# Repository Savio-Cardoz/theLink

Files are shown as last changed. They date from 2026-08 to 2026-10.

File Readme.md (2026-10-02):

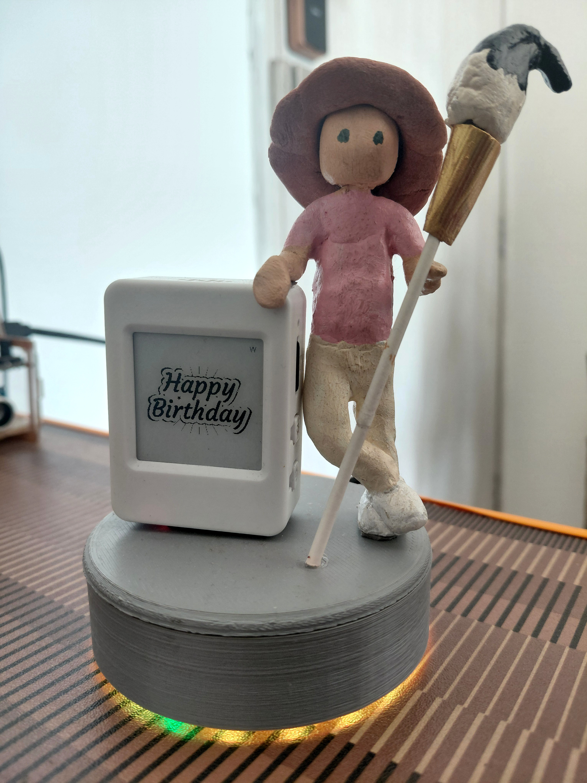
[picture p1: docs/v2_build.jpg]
theLink


# theLink

theLink is a device to send a surprise to a friend that quietly turns up on their
desk — no buzzing phone, no notification. The message arrives as a picture on
the e-paper screen, a glow from the LED ring, maybe a sound from the speaker.

Everything lives on one small waveshare unit, and one extra ring of LEDs makes it glow.

- Built right in: 1.54-inch e-paper display, ESP32-S3 (Wi-Fi + Bluetooth), speaker, microphone, microSD card reader
- I've added a 16-LED NeoPixel ring (the notification LED)
- Messages arrive over Wi-Fi via MQTT (default broker: `mqtt://broker.emqx.io`)
- First-time setup over Bluetooth by scanning a QR code

---

## 1. What is it

**The unit** — a Waveshare 1.54-inch ESP32-S3 e-paper module. It comes as one
package and already contains:

| Piece | What it does |
|---|---|
| E-paper display (200x200) | Shows images, all day, with almost no power |
| ESP32-S3 chip | The brain — Wi-Fi + Bluetooth built in |
| Speaker | Plays sound files |
| Microphone | (available for future projects) |
| microSD reader | Stores images and sounds on a card |
| SHTC3 temperature + humidity sensor | Reports the air around it, every 5 minutes |
| PCF85063 real-time clock | Keeps the time across a restart, so a rebooted unit needs no network to know it. Runs on the board's 3v3 rail, so it does not survive a power cut |

**Additional**

| Piece | Why |
|---|-----|
| 16-LED NeoPixel ring | The glowing "notification LED", data pin wired to GPIO 2 |
| microSD card (FAT32) | Holds the images and sounds the device downloads |
| USB-C data cable | For the one-time software flash |
| External Button  | For the one-time Wi-Fi setup (Bluetooth) |
| Computer | For the one-time software flash |
| Android phone | For the ESP BLE Provisioning app and IoTHome MQTT dashboard builder app.

**Software you'll use:**

- **MQTTX** — a free app (desktop or phone) for sending and watching messages. This is how the surprise travels to my friend's via theLink.
- **Espressif Provisioning** app (phone) — scans the QR code on the e-paper to give the device a Wi-Fi name and password.

---

## 2. First power-up

1. **Flash the software once.** This needs the ESP-IDF environment set up first
   (only once per computer, and repeated for every new terminal):

   ```powershell
   $env:IDF_PATH = "C:\Espressif\frameworks\esp-idf-v5.4.1"
   & "$env:IDF_PATH\export.ps1"
   ```

   Then, from the project folder:

   ```bash
   python3 scripts/build.py flash
   ```

2. **Reset Provisioning:** hold the reset button at the rear
   (GPIO 3) down while powering it up and keep holding for about 1 second.
3. **Power on.** After a moment the e-paper shows a QR code and the LED ring starts pulsing.
4. **Add Wi-Fi:** open the Espressif Provisioning app, scan the QR code, and enter the Wi-Fi network name and password.
5. **Done.** The LED ring stops pulsing once it connects — the device is ready.

### LED ring indicators during provisioning

The ring shows which stage of setup it is in:

| Effect | What it means |
|---|---|
| Fast blue pulse (every 0.5 s) | Provisioning is active — it's waiting for a phone |
| Medium blue pulse (every 1.5 s) | A phone is connected over Bluetooth |
| Slow blue pulse (every 3 s) | It connected to the Wi-Fi |
| Ring does behaves as MQTT messages say | Setup is complete |

---

## 3. MQTT Communication

MQTT is how a message travels from me to my friend's theLink over Wi-Fi. It works like a post office:

- **Broker** = the post office in the middle (there's a free public one at `broker.emqx.io`).
- **Topic** = a mailbox name. The device checks certain mailboxes and ignores the rest.
- **Message** = the letter inside the mailbox. JSON text

**Heads-up:** `0A1B2C3D4E5F` in the topics below is a placeholder — it stands for
the 6-byte MAC address of the ESP32 chip in use. Section 4 shows 
how to find the MAC and swap it in.

Topics come in two flavours:

| Kind | Looks like | Meaning |
|---|---|---|
| `cmd/` (commands) | `thelink/0A1B2C3D4E5F/cmd/rgb` | Mailboxes the device **reads** — where to post messages |
| `evt/` (events) | `thelink/0A1B2C3D4E5F/evt/led` | Mailboxes the device **writes** — its replies |

**First 60 seconds with MQTTX:**

1. Open MQTTX and add a connection to `broker.emqx.io` (port `1883`).
2. Subscribe (listen) to topic `thelink/0A1B2C3D4E5F/evt/#` (remember: replace `0A1B2C3D4E5F` with device's ID).
3. Publish (send) to topic `thelink/0A1B2C3D4E5F/cmd/rgb` this message:

   ```json
   { "pattern": "rainbow_cycle" }
   ```

4. The ring goes rainbow. First message delivered

If you built the firmware with a broker URL or credentials (see
[MQTT broker settings](#mqtt-broker-settings)), MQTTX has to point at the same
broker, with the same username and password.

---

## 4. Find the device ID

Every example in this guide uses the placeholder device ID `0A1B2C3D4E5F`.
**Your device has its own.** It is the 6-byte factory MAC address of your board,
written as uppercase hex with no dashes — format `UUVVWWXXYYZZ`.

How to see yours:

- **Boot log:** the serial monitor prints `Device ID: UUVVWWXXYYZZ` at startup.

Whatever it is, swap it in wherever you see `0A1B2C3D4E5F` below.

---

## 5. The messages you can send — copy and paste ready

Pick a section, copy the topic, copy the message, and paste them into MQTTX.

### 5.1 Show an image — `cmd/display`

Downloads a picture from the server, saves it on the SD card, and shows it on the e-paper.

- **Topic:** `thelink/0A1B2C3D4E5F/cmd/display`
- **Publish this:**

  ```json
  {
    "download": "http://example.com/myphoto.bin",
    "filename": "myphoto.bin"
  }
  ```
- **You should see:** the e-paper refresh and show the new image.

| Field | Type | Required | Description |
|---|---|---|---|
| `download` | string | Yes | The web address (URL) of the image |
| `filename` | string | Yes | What to call the file on the SD card (`/sdcard/…`) |

**Before you send an image — turn your photo into e-paper format.**

The screen is monochrome and 200x200. Ordinary JPG/PNG files won't work: you first
convert yours into the special `.bin` format the screen understands, host it on your
own HTTP server, then point the message at it.

1. **Convert your photo** with the included script (run it on your computer, in the
   project folder):

   ```bash
   python3 scripts/png_to_epaper.py myphoto.png myphoto.bin
   ```

   Useful extra options: `--threshold <0-255>` (brightness cut-off, default 128),
   `--invert` (swap black and white), and `--preview` (saves a `_preview.png` so you
   can check the result before sending).

2. **Host the file on your own HTTP server** — it must be reachable from the device.
   The quickest way, from the folder containing the `.bin`:

   ```bash
   python3 -m http.server
   ```

   Now your file is available at `http://<your-server-ip>:8000/myphoto.bin`.

3. **Use that link as `download`** — the URL of the `.bin` on your server goes into
   the message:

   ```json
   {
     "download": "http://192.168.1.50:8000/myphoto.bin",
     "filename": "myphoto.bin"
   }
   ```

Notes: images must be LVGL I8 format (indexed 8-bit, 200x200, with a 256-colour
palette) — exactly what `png_to_epaper.py` produces.

---

### 5.2 The RGB LED ring — `cmd/rgb`

The most fun one. The ring has 16 LEDs and supports patterns, colours, brightness,
per-LED colours, and an auto-off timer. Every field is optional — only send what you
want to change.

- **Topic:** `thelink/0A1B2C3D4E5F/cmd/rgb`

**Solid colour:**

```json
{
  "enable": true,
  "pattern": "solid_color",
  "color": { "h": 210, "s": 100, "v": 60 }
}
```

**Rainbow slowly cycling:**

```json
{
  "pattern": "rainbow_cycle",
  "speed": 40
}
```

**Per-LED colours (LED 0 red, LED 1 green, LED 2 off, rest skipped):**

```json
{
  "pixels": ["#FF0000", "#00FF00", null],
  "brightness": 75
}
```

**Turn on, then off by itself after 30 seconds (timer + colour as hex):**

```json
{
  "pattern": "scanner",
  "color": "#00AAFF",
  "duration": 30
}
```

**Turn the ring off:**

```json
{ "enable": false }
```

- **You should see:** the ring change immediately, and a reply arrive on `evt/led` with the new state.

**Patterns you can use:**

| Pattern | Description |
|---|---|
| `off` | Turn the strip off |
| `solid_color` | Single steady colour |
| `rainbow_cycle` | Smooth rainbow cycling across all LEDs |
| `theater_chase` | Theatre-style chasing lights |
| `color_wipe` | One colour wipes across the ring |
| `scanner` | A light sweeping back and forth |
| `fade` | Gentle breathing fade |

**All the fields:**

| Field | Type | Values / default | Description |
|---|---|---|---|
| `enable` | bool | `true` / `false` | Master on/off; `false` turns the ring off immediately |
| `pattern` | string | see table above | Which pattern to run (also switches the ring on) |
| `color` | string or object | `"#RRGGBB"`, or `{"h":0-360,"s":0-100,"v":0-100}`, or `{"r","g","b":0-255}` | The colour to use |
| `brightness` | number | 0–100 (default 100) | Global brightness, dims everything |
| `speed` | number | 5–5000 ms (default 20) | How fast patterns animate — lower is faster |
| `pixels` | array | up to 16 entries | Colour each LED by hand; `null` skips an LED and overrides `pattern` while present |
| `duration` | number | seconds | Auto-off after this long (0 or absent = stay on) |
| `persist` | bool | default `true` | Save the state to the SD card so it survives a reboot |

---

### 5.3 Notification alert — `cmd/notification`

A shortcut that turns on the ring with a pattern (the same patterns as `cmd/rgb`).

- **Topic:** `thelink/0A1B2C3D4E5F/cmd/notification`
- **Publish this:**

  ```json
  {
    "message": "scanner"
  }
  ```

- **You should see:** the ring start the `scanner` pattern.

| Field | Type | Required | Description |
|---|---|---|---|
| `message` | string | Yes | Pattern name (same list as section 5.2) |

---

### 5.4 Play a sound — `cmd/audio`

Plays an audio file through the speaker. The file can already be on the SD card,
or the device can download it first.

**Play a file already on the SD card:**

- **Topic:** `thelink/0A1B2C3D4E5F/cmd/audio`
- **Publish this:**

  ```json
  {
    "download": "",
    "filename": "alert.wav",
    "volume": 80
  }
  ```

**Download a file, then play it:**

  ```json
  {
    "download": "http://example.com/alert.wav",
    "filename": "alert.wav",
    "volume": 80
  }
  ```

- **You should hear:** the sound over the speaker.

| Field | Type | Required | Description |
|---|---|---|---|
| `download` | string | Yes | Web address of the sound — use an empty string `""` if the file is already on the SD card |
| `filename` | string | Yes | The file to play (saved to `/sdcard/…` when downloading) |
| `volume` | number | No | Volume 0–100 |

---

### 5.5 Update the firmware — `cmd/ota`

Downloads a brand-new version of the device software, shows "Update in progress"
on the screen, then restarts itself with the new code.

- **Topic:** `thelink/0A1B2C3D4E5F/cmd/ota`
- **Publish this:**

  ```json
  {
    "download": "https://example.com/theLink_esp32s3.bin",
    "version": "0.4.0"
  }
  ```

- **You should see:** "Update in progress" on the e-paper, then the device reboots.
  Progress replies arrive on `evt/ota` (`started`, `downloaded`, `rebooting`, `failed`).

| Field | Type | Required | Description |
|---|---|---|---|
| `download` | string | Yes | Web address of the firmware file (an ESP-IDF app image `.bin`) |
| `version` | string | No | Just for the logs and events |

Like images (section 5.1), the firmware file must first exist on your own HTTP
server — put the `.bin` somewhere the device can reach and point `download` at
that file's URL. No conversion step is needed; the firmware is already an ESP-IDF
app image.

---

### 5.6 Control the logs — `cmd/log`

Changes how loudly the device talks on `evt/log`. Handy when debugging.

- **Topic:** `thelink/0A1B2C3D4E5F/cmd/log`

**Set the log level to debug (most talkative):**

```json
{
  "action": "set_level",
  "level": "debug"
}
```

**Check the current level:**

```json
{
  "action": "get_level"
}
```

| Field | Type | Required | Description |
|---|---|---|---|
| `action` | string | Yes | `"set_level"` or `"get_level"` |
| `level` | string | for `set_level` | `"error"`, `"warn"`, `"info"`, `"debug"`, `"verbose"`, or `"none"` |

---

### 5.7 Check on the status of theLink — `cmd/status`

Query the device for its status, what is its state.

- **Topic:** `thelink/0A1B2C3D4E5F/cmd/status`

**Ask for the status (any payload works, even an empty one):**

```json
{}
```

- **You should see:** a reply on `evt/status` (section 6) with the current
  firmware version, the LED pattern, the image on the e-paper, the current time
  and where it came from, how much room is
  left on the SD card and a few
  supporting details.

The command takes no fields — it is a bare query, so an empty message is fine.
Nothing is changed by sending it, and the reply is **not** retained.

---

### 5.8 Set the timezone — `cmd/timezone`

Tell the device where it is, so it can report local time and not just UTC. It
does not look this up from the IP address: you declare it.

- **Topic:** `thelink/0A1B2C3D4E5F/cmd/timezone`

**For India (IST, UTC+05:30):**

```json
{
  "tz": "IST-5:30"
}
```

**For Germany in summer (CEST, UTC+02:00):**

```json
{
  "tz": "CEST-2"
}
```

| Field | Type | Required | Description |
|---|---|---|---|
| `tz` | string | Yes | The timezone as a POSIX string (see below) |

**The sign is inverted, and this trips everyone up.** A POSIX offset is the time
you **add to local time to reach UTC**. India is ahead of UTC by 5½ hours, so it
is `-5:30`, not `+5:30`. Writing `IST+5:30` would put the device five and a half
hours *behind* UTC.

**This is not an IANA name.** `"Asia/Kolkata"` will be rejected with a note in
the log rather than silently doing nothing, because the C library in this firmware
ships no timezone database to resolve it against. Use the POSIX form — any label
you like (`IST`, `CET`, whatever) followed by the offset.

The device logs the offset it actually ended up applying, so check the serial log
or `evt/log` if the local time looks wrong:

```
I (1234) TIME: timezone "IST-5:30" applied, UTC offset is +05:30
```

The setting is written to the SD card and survives a reboot. The `THELINK_TZ`
build option is only a factory default for a card that has never been told
otherwise.

**Daylight saving is not automatic.** A fixed offset like `IST-5:30` is correct
year-round for India, but a place that changes its offset will need a new
`cmd/timezone` when it does.

---

## 6. What the device sends back (events)

These are mailboxes the device **writes** to. Subscribe to them to watch what
theLink is doing.

### `evt/led` — the ring's state (retained)

Every time the ring accepts a command, the device replies with the full current
state. The message is **retained**, so anyone who subscribes later immediately
gets the latest state — no need to wait.

- **Topic:** `thelink/0A1B2C3D4E5F/evt/led`

```json
{
  "active": true,
  "pattern": "rainbow_cycle",
  "color": { "h": 210, "s": 100, "v": 60 },
  "brightness": 75,
  "speed": 40,
  "pixels": ["#FF0000", null],
  "cmd_id": 12
}
```

### `evt/ota` — firmware update progress

- **Topic:** `thelink/0A1B2C3D4E5F/evt/ota`

```json
{
  "status": "downloaded",
  "detail": "/sdcard/update.bin"
}
```

`status` is one of `started`, `downloaded`, `rebooting`, or `failed`.

### `evt/sensor` — temperature and humidity (retained)

The built-in SHTC3 sensor takes a reading shortly after boot and then every
5 minutes. The message is **retained**, so a dashboard that subscribes at any
time immediately gets the most recent reading instead of waiting for the next
one, and the device re-publishes it every time it reconnects to the broker.

- **Topic:** `thelink/0A1B2C3D4E5F/evt/sensor`

```json
{
  "temperature_c": 24.31,
  "humidity_pct": 41.19,
  "age_ms": 12430
}
```

| Field | Type | Description |
|---|---|---|
| `temperature_c` | number \| null | Air temperature in degrees Celsius |
| `humidity_pct` | number \| null | Relative humidity, 0-100 |
| `age_ms` | number | How long ago this reading was taken. Absent when there is no reading |

This topic is **publish-only** — there is no `cmd/sensor` command, because
there is nothing to configure about a thermohygrometer. To read the value right
now, use `cmd/status` (section 5.7), which folds the same numbers into its
`sensor` object.

If a read fails (sensor not yet powered, bus error, or a bad checksum) the
device logs a warning and keeps the previous reading rather than publishing a
blank one, so a stale number is never silently replaced by `null`. The
temperature and humidity fields are `null` only until the very first successful
sample. Each read is attempted three times before the cycle gives up, and the
first attempt is held back until about two seconds after boot so it does not
race the audio codec coming up on the same I2C bus.

At boot the driver also reads the sensor's ID register and logs it, e.g.
`SHTC3: ID 0x0910 (CRC ok)`. That is the quickest way to tell a working sensor
from a dead one: no ID line, or a CRC failure, means the part never identified
itself. See the troubleshooting table (section 7).

### `evt/status` — answer to `cmd/status`

- **Topic:** `thelink/0A1B2C3D4E5F/evt/status`

```json
{
  "version": "0.4.0",
  "rgb_pattern": "rainbow_cycle",
  "image": "/sdcard/dog.bin",
  "device_id": "0A1B2C3D4E5F",
  "sensor": {
    "temperature_c": 24.31,
    "humidity_pct": 41.19,
    "age_ms": 12430
  },
  "time": {
    "utc": "2026-09-26T06:12:33Z",
    "epoch_s": 1788297153,
    "local": "2026-09-26T11:42:33+05:30",
    "tz": "IST-5:30",
    "source": "sntp",
    "synced": true,
    "age_ms": 51230,
    "rtc": { "present": true, "valid": true }
  },
  "partition": "ota_0",
  "uptime_ms": 128430,
  "free_heap": 214032,
  "min_free_heap": 180112,
  "sdcard": { "mounted": true, "total_bytes": 31914983424, "free_bytes": 30012345678 },
  "build": { "date": "Sep 26 2026", "time": "11:42:07", "idf": "v5.4.1" }
}
```

| Field | Type | Description |
|---|---|---|
| `version` | string | Firmware version (matches `version.txt`) |
| `rgb_pattern` | string | LED pattern currently selected — one of `off`, `solid_color`, `rainbow_cycle`, `theater_chase`, `color_wipe`, `scanner`, `fade` |
| `image` | string \| null | Full SD path of the image **currently on the e-paper**, or `null` if nothing has been rendered yet |
| `device_id` | string | Same device ID you used in the topic |
| `sensor` | object | Cached temperature and humidity — `temperature_c`, `humidity_pct`, and `age_ms`. `null` values until the first sample succeeds. Same contents as `evt/sensor` |
| `time` | object | The current time, where it came from, and the RTC's state. See the table below |
| `partition` | string \| null | App partition being executed (`ota_0` in a production build) |
| `uptime_ms` | number | Milliseconds since boot |
| `free_heap` | number | Free internal heap, in bytes |
| `min_free_heap` | number | Lowest free heap reached since boot, in bytes |
| `sdcard` | object \| null | `mounted`, `total_bytes` and `free_bytes` of the SD card, or `null` if no card is present |
| `build` | object | `date`, `time` and IDF `version` of this build. Omitted if the build has no compile timestamp |

`image` only advances once a picture has been unpacked and pushed to the screen,
so it never claims to be showing an image that failed to download or render.
It starts out as `null` after a reboot and fills in once the e-paper has been
drawn.

`sensor` is a cache, not a live read: asking for the status never blocks on I2C,
so it stays fast. Use `age_ms` to tell a fresh reading from one taken at boot.

`sdcard` is `null` rather than zeroed when the card is absent, so a missing card
is never mistaken for a full one. Its sizes describe the FAT volume, meaning
filesystem overhead is already excluded — the numbers are what you can actually
store, not the card's advertised capacity.

#### The `time` object

| Field | Type | Description |
|---|---|---|
| `utc` | string \| null | The time in UTC, ISO 8601 with a `Z` suffix. `null` if no time has been established yet |
| `epoch_s` | number \| null | The same instant as a Unix timestamp |
| `local` | string \| null | Local time with its offset, e.g. `2026-09-26T11:42:33+05:30`. `null` until a timezone is declared |
| `tz` | string \| null | The timezone string in force, e.g. `IST-5:30`. `null` if none was ever set |
| `source` | string | `sntp` (corrected against an NTP server), `rtc` (restored from the RTC on boot), or `none` |
| `synced` | boolean | `true` only when `source` is `sntp` |
| `age_ms` | number \| null | How long ago the time was last established. `null` when it never has been |
| `rtc.present` | boolean | Whether a PCF85063 real-time clock answered on the I2C bus |
| `rtc.valid` | boolean | Whether the RTC is holding a calendar worth reading, either because it survived the last restart or because it was written since. `false` after a power cut, until SNTP writes it |

`source` is the field worth watching. A device showing `sntp` is telling the
truth. One showing `rtc` has restored its clock from the RTC and is running on that
until the network catches up — as trustworthy as a drift-free crystal, but not yet
confirmed. `none` means no time has been established at all, which is the expected
state straight after a power cut.

`local` and `tz` stay `null` until you send `cmd/timezone` (section 5.8). The
device does not assume UTC, because a dashboard that silently renders 5:30 as
"local" is worse than one that says it does not know.

The device syncs to `pool.ntp.org` as soon as it has a network address, and
re-checks hourly. It also keeps a PCF85063 real-time clock, which it writes on every
sync and reads at boot, so a unit that reboots without Wi-Fi still reports the right
time. That is the limit of it: the RTC is powered from the board's 3v3 rail and
there is no backup cell fitted, so a power cut resets it and the unit has to reach
SNTP before it knows the time. `source: none` on a freshly plugged-in unit is
expected, not a fault.

### `evt/log` — the device's diary

- **Topic:** `thelink/0A1B2C3D4E5F/evt/log`

```json
{
  "device_id": "0A1B2C3D4E5F",
  "level": "info",
  "tag": "app",
  "msg": "Display download complete"
}
```

---

## 7. Troubleshooting

| Problem | Try this |
|---|---|
| LED ring does nothing | Check power; make sure you flashed the firmware (section 2); check Data line connection |
| Ring pulses forever after setup | Wi-Fi credentials didn't save — factory reset (hold reset ~1 s at boot) and re-provision |
| Screen stays blank | Check the SD card is inserted, formatted FAT32, and your file was downloaded (watch `evt/led` isn't enough — check `evt` and the serial log) |
| Nothing happens / no `evt/led` reply | Wrong device ID in the topic, or the broker address doesn't match. Verify the device ID in the boot log |
| Image doesn't show | Convert it first with `python3 scripts/png_to_epaper.py` — it must be LVGL I8, 200x200, with a 256-colour palette, and hosted on your own HTTP server |
| Sound doesn't play | File must exist on the SD card (use `"download": ""` for a file already there) |
| `evt/sensor` never arrives | Start with `ID 0x….  (CRC ok)` and `SHTC3 attached at 0x70`, then the `I2C scan on SDA 47 / SCL 48:` line printed about two seconds after boot, which lists the addresses that answered. Treat it as a rough indication, not a device list: it shares the bus with the audio codec, and a probe that loses the bus to another task can miss a device that is working. A `swept 0x08..0x77:` line follows it with the totals (answered / did not acknowledge / timed out), and `sweep missed 0x…` warns outright when the scan contradicts a device that just answered — when you see that, the scan is wrong, not the device. The per-device attach lines (`SHTC3 attached at 0x70`, `PCF85063 attached at 0x51`) are the reliable evidence. A failed attach, or an `ID read 0xEFC8 NACKed at 0x70` at attach, is hardware — the sensor never identified itself. If the ID verifies but a read still fails, `measurement command 0x7866 NACKed at 0x70` means it answered the probe and the identity read but not the measurement, and `CRC mismatch` means the bus is noisy. A read is retried three times per cycle, then left to the next 5-minute tick |
| `time.source` stays `rtc` or `none` | SNTP has not completed. `TIME: SNTP started against pool.ntp.org` means it was started, so look for `synchronized with pool.ntp.org`. The device waits 2 minutes for the first correction and then logs that none arrived, but lwIP keeps retrying in the background and a later correction sets the clock as normal, so that warning alone is not a failure. If it never corrects, the network is blocking UDP 123, or DNS cannot resolve the pool. `none` is the expected state after a power cut until SNTP lands, because the RTC is powered from 3v3 and resets with the board; it is only a fault if it persists after the unit has synced once |
| `time.local` is `null` | No timezone has been declared. Send `cmd/timezone` (section 5.8) |
| `time.local` is hours off | The POSIX sign is inverted. `IST+5:30` is *behind* UTC by 5½ hours; India is `IST-5:30`. The device logs the offset it applied — `timezone "…" applied, UTC offset is +05:30` — so check that line against what you expected |
| `cmd/timezone` is ignored | Look for the reason in the log. A payload with no `tz` string, one that isn't JSON, or an IANA name containing `/` is rejected outright rather than applied |

---

## 8. Advanced: building and flashing (for maintainers)

This section is for the people updating the software itself. If you just want to
use the device, you can stop reading here.

### ESP-IDF environment

The IDF tools live in `$env:IDF_PATH`, which must point at an ESP-IDF install that
actually has its toolchain installed (e.g. `C:\Espressif\frameworks\esp-idf-v5.4.1`
for the Espressif installer layout). Tools and toolchains are not tied to a bare
`git clone` — running export from such a clone fails with `tool ... has no
installed versions`.

In a new PowerShell terminal:

```powershell
$env:IDF_PATH = "C:\Espressif\frameworks\esp-idf-v5.4.1"
& "$env:IDF_PATH\export.ps1"
```

Notes:

- Export must be repeated in every new terminal (environment variables are per-session).
- A stale `IDF_PATH` overrides the new value inside already-open terminals — restart after changing it.
- `scripts/build.py` and `scripts/flash_all.py` auto-locate the ESP-IDF Python environment, so they work without the export (the export is still needed to call `idf.py`, `esptool.py`, or `menuconfig` directly).
The project uses my [esp32_factory_app](https://github.com/Savio-Cardoz/esp32_factory_app.git) repo as the update flashing app. This app resides in the factory parition.

### Build profiles

A single switch selects the build profile. **Dev is the default** — a plain
`python3 scripts/build.py` gives a development build.

- **Dev** (default) — standard partition table **without OTA** (`partitions_dev.csv`). Flashed straight to the `factory` partition; the `esp32_factory_app` bootloader is not used. Builds go to `build-dev`.
- **Prod** — production partition table for OTA via the `esp32_factory_app` bootloader (`partitions.csv`: `factory` + `ota_0`). Builds go to `build`.

```bash
# Development build (no OTA) — default profile
python3 scripts/build.py
python3 scripts/build.py flash

# Production build (esp32_factory_app OTA)
python3 scripts/build.py -p Prod
python3 scripts/build.py -p Prod flash
```

Manual equivalents:

```bash
python3 $IDF_PATH/tools/idf.py -B build-dev build
python3 $IDF_PATH/tools/idf.py -B build-dev flash
python3 $IDF_PATH/tools/idf.py -B build -DSDKCONFIG_DEFAULTS="sdkconfig.defaults;sdkconfig.prod" build
```

For production, the main app is flashed to the `ota_0` partition and the
`factory` partition holds the bootloader app. Flash the whole stack (bootloader,
partition table, otadata, factory app + main app) with:

```bash
python3 scripts/flash_all.py -p COM6
```

### Configuration

Build-time options in `menuconfig` (`Example Configuration`):

| Option | Default | Description |
|---|---|---|
| `CONFIG_BROKER_URL` | `mqtt://broker.emqx.io` | MQTT broker address |
| `CONFIG_MQTT_USERNAME` | `""` | MQTT username (usually set at build time, see below) |
| `CONFIG_MQTT_PASSWORD` | `""` | MQTT password (usually set at build time, see below) |

#### MQTT broker settings

The first time you build, `scripts/build.py` asks for the broker URL and its
credentials and remembers them:

```
Broker URL [mqtt://broker.emqx.io]: mqtts://my-broker.example.com:8883
MQTT username: thelink
MQTT password: ********
Confirm password: ********
  broker url      : mqtts://my-broker.example.com:8883 (the prompt)
  mqtt username   : thelink (the prompt)
  saved to        : sdkconfig.secrets
```

They are stored in `sdkconfig.secrets`, a Kconfig overlay that the build appends
to `SDKCONFIG_DEFAULTS`. The file is gitignored, so the credentials never reach
the repository. Later builds read it silently — you answer the prompt once.

| Setting | Kconfig option | Environment variable |
|---|---|---|
| Broker URL | `CONFIG_BROKER_URL` | `THELINK_BROKER_URL` |
| Username | `CONFIG_MQTT_USERNAME` | `THELINK_MQTT_USERNAME` |
| Password | `CONFIG_MQTT_PASSWORD` | `THELINK_MQTT_PASSWORD` |

All three are ordinary menuconfig options as well, so you can set them by hand
if you prefer. **Leaving a field empty means "not specified"**: that field is
not written to the overlay and the menuconfig value keeps applying. The Broker
URL prompt is pre-filled with the URL the last build used, so pressing Enter
leaves your menuconfig broker alone rather than pinning a copy of it. A typed
URL is checked before it is accepted — it needs a host and one of the four
schemes esp-mqtt understands (`mqtt`, `mqtts`, `ws`, `wss`) — so a typo fails
at build time rather than on the device.

**Skipping the prompt is fine.** Press Enter at the username prompt and the
build carries on with no credentials, exactly as firmware before v0.4.0 did —
which is what an unauthenticated public broker such as `broker.emqx.io` wants.
The firmware logs a warning at boot and connects anonymously; a broker that
requires authentication will refuse the connection.

```bash
# Change the broker settings later
python3 scripts/build.py --reprompt

# Never be asked: use the cache if there is one, menuconfig if not
python3 scripts/build.py --no-prompt

# Supply them non-interactively (CI, scripted builds)
THELINK_BROKER_URL=mqtts://broker:8883 THELINK_MQTT_USERNAME=thelink \
  THELINK_MQTT_PASSWORD=... python3 scripts/build.py
```

Environment variables take precedence over the cached file, and
`sdkconfig.secrets` is rewritten to match whichever source won, so the file
always reflects the last build. `sdkconfig.secrets.example` documents the file
format.

> **Note:** the settings are compiled into the firmware, and also land in
> `build*/sdkconfig` and `build*/config/sdkconfig.h` (both gitignored). Treat
> the built binary as sensitive. Credentials alone are not much use over the
> wire — point `CONFIG_BROKER_URL` at an `mqtts://` endpoint to get TLS as
> well.

---

## 9. Version history
### v0.4.1
- Time synchronization over SNTP (`pool.ntp.org`), re-checked hourly
- On-board PCF85063 real-time clock, read at boot to seed the system clock and
  rewritten from SNTP on every sync, so a unit that reboots without a network
  still tells the time. It is powered from 3v3, so a power cut resets it and SNTP
  becomes the only source until it lands
- New `time` object in the `evt/status` reply: `utc`, `epoch_s`, `local`, `tz`,
  `source` (`sntp` / `rtc` / `none`), `synced`, `age_ms`, and the RTC's
  `present` / `valid` state
- New `cmd/timezone` command (section 5.8), so `local` can be reported as a real
  local time rather than left unset
- The device republishes a full status after every successful sync and on every
  MQTT reconnect, so a dashboard that subscribes late still gets the corrected
  time
- New `cmd/timezone` command to declare where the device is, persisted to
  `config.json` so it survives a reboot
- `THELINK_TZ` build option as a factory default for a unit never told otherwise;
  the stored timezone wins over it

### v0.4.0
- On-board SHTC3 temperature and humidity sensor
- New retained `evt/sensor` event, published at boot and then every 5 minutes,
  and re-published on every MQTT reconnect
- `cmd/status` now includes the cached reading in a `sensor` object
- New shared `i2c_bsp` component owning the board I2C bus, so the codec and the
  sensor share one bus instead of each creating their own
- Failed sensor reads keep the last good reading rather than publishing `null`
- MQTT broker settings asked for at build time: the broker URL
  (`CONFIG_BROKER_URL`) and its credentials (`CONFIG_MQTT_USERNAME` /
  `CONFIG_MQTT_PASSWORD`), sent to the broker on connect
- `scripts/build.py` asks for them on the first build and caches them in the
  gitignored `sdkconfig.secrets`; an empty answer leaves that setting to
  menuconfig
- `scripts/build.py --reprompt` to change them, `--no-prompt` to never be asked,
  and `THELINK_BROKER_URL` / `THELINK_MQTT_USERNAME` / `THELINK_MQTT_PASSWORD`
  to supply them non-interactively
- Credentials stay optional: skipping the prompt builds firmware that connects
  anonymously, as before, and says so in the log

### v0.3.1
- `cmd/status` device-status query: firmware version, current LED pattern and
  the image on the e-paper, plus partition, uptime, heap and build details
- SD card size and free space added to the `evt/status` reply as a `sdcard`
  object, `null` when no card is present

### v0.3.0
- Per-subsystem MQTT topics with dedicated handlers
- Dispatch table architecture for topic-based command routing
- Global MQTT client handle for future publish use
- Notification LED pulses reflect provisioning states (0.5 / 1.5 / 3 s)
- QR code on the e-paper for Wi-Fi provisioning
- Button to re-provision
- Expanded control of LED colour, pattern and timing
- LED on/off control
- Avoids re-downloading files already on the SD card
- Updated OTA mechanism with verify (PENDING_VERIFY → confirm on boot)

### v0.2.0
- RGB LED strip control via MQTT (patterns, per-LED colours, brightness, speed, auto-off)
- `RgbLedStrip` class with `runPattern()` interface
- Pattern selection via MQTT `notification` command

### v0.1.0
- MQTT v5 protocol support
- E-paper display image download and render
- Wi-Fi provisioning (BLE)
- SD card image storage

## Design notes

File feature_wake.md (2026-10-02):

# Feature — Always-on Wake Word ("Hi,ESP")

Status: **design complete, not implemented**
Target: Waveshare ESP32-S3-ePaper-1.54 (ES8311 codec + one analog mic)
Wake word: bundled ESP-SR WakeNet9 model `wn9_hiesp`, spoken phrase **"Hi,ESP"**

---

## 1. Summary

Add a low-priority FreeRTOS task that keeps the ES8311 microphone open and streams
16 kHz mono PCM into ESP-SR's standalone WakeNet9 engine. On a detection the device
publishes an MQTT event, flashes the LED ring, and plays an acknowledgement sound from
the SD card.

The model ships on the SD card (`CONFIG_MODEL_IN_SDCARD=y`), so there is no flash
partition, no partition-table change, and no OTA interaction with model data.

The single hard problem is that playback and capture share **one** ES8311 codec and
**one** I2S data interface. Every other item in this document is straightforward once
that is solved (see §4.2 and §5.3).

---

## 2. Decision record

| Decision | Choice | Rationale |
| --- | --- | --- |
| Wake word | `wn9_hiesp` = "Hi,ESP" | Bundled with ESP-SR, no training or vendor request needed. |
| Engine | Standalone `esp_wn_iface_t` (no AFE) | No AEC/VAD/NS requested for phase 1; ~13% of one core, 20 KB IRAM, 347 KB PSRAM. |
| Model storage | SD card, `CONFIG_MODEL_IN_SDCARD=y` | User choice. Keeps app flash for OTA. |
| Always-on | Yes, task starts after SD mount | Wake available with no button press. |
| On detection | MQTT event + LED flash + ack sound from SD | User choice (both answers in the questionnaire). |
| Listening during playback | Paused | No AEC; self-triggering is worse than missing a wake word while the device is talking. |
| NS / AEC / VAD | Off for phase 1 | Deliberate. See §8 for the follow-up if false alarms dominate. |
| Sensitivity | Runtime threshold via `wn->set_det_threshold()` | Confirmed available in the standalone interface (`esp_wn_iface.h`). |
| Custom model ("Hi Link") | Deferred | User chose the bundled phrase for now. Requires a separate project; see §10. |

---

## 3. Assumptions

Each item is marked **[V]** verified by reading the repository / ESP-SR source, or
**[A]** assumed and to be confirmed on hardware.

### 3.1 Hardware

* **[V]** Microphone is the ES8311 ADC line, not a raw-ADC input: I2S `mclk=14`, `bclk=15`,
  `din=16`, `ws=38`, `dout=45` (`components/codec_board/board_cfg.txt`,
  `codec_init.c:397-470`), codec type `S3_ePaper_1_54` (`audio_bsp.c:20`).
* **[V]** The mic amplifier enable is `pa_pin = GPIO46`; `esp_codec_dev_open(record, …)`
  drives it high through `es8311_pa_power()`, and `esp_codec_dev_close(playback, …)`
  drives it low.
* **[A]** PA polarity is active-high (matches `es8311_pa_power`). Confirm in P0 by toggling
  GPIO46 and listening for speaker output.
* **[A]** One microphone only. If `wn9_hiesp` reports `get_channel_num() == 3`, mono input is
  duplicated into 3 interleaved channels — see §7 OQ-1.
* **[A]** PSRAM is 8 MB. `sdkconfig.defaults:18-20` only proves octal PSRAM is enabled;
  capacity was never confirmed from the vendor spec. Relevant because the model is loaded
  to PSRAM (`DET_MODE_95*`).
* **[A]** Mic gain of 30 dB (the current default, `codec_init.c:534-536`) is adequate for
  0.5–1 m talk distance. P0 logs RMS dBFS so the gain can be tuned from real data.

### 3.2 ESP-SR / toolchain

* **[V]** Local ESP-IDF is v5.4.1 (`sdkconfig.defaults` header comment says 5.5.1); ESP-SR
  supports IDF ≥ 5.0, so v5.4.1 is fine.
* **[V]** `espressif/esp-sr` is delivered as prebuilt static libraries per target
  (`esp-sr/CMakeLists.txt`), including `libwakenet.a`. No esp-dl kernel source build.
* **[V]** `esp-sr/CMakeLists.txt` only emits the `srmodels_bin` target when a partition named
  `model` exists in the custom partition table. `partitions_dev.csv` has none, so with
  SD-card loading the build prints "Failed to find model in partition table file" and moves on.
  **No partition-table change is required.**
* **[V]** `det_mode_t`: `DET_MODE_90`/`DET_MODE_95` (1 ch, flash/PSRAM) and
  `DET_MODE_2CH_90/95`, `DET_MODE_3CH_90/95` (PSRAM variants). PSRAM modes are mandatory here.
* **[V]** `esp_wn_iface_t` exposes `get_channel_num()`, `get_samp_chunksize()`,
  `get_samp_rate()`, `set_det_threshold(model, thr, word_index)` (range 0.4–0.9999,
  index starts at 1), `get_triggered_channel()`, `clean()`, `destroy()`.
* **[V]** `detect()` returns `wakenet_state_t`: `WAKENET_NO_DETECT`, `WAKENET_CHANNEL_VERIFIED`,
  `WAKENET_DETECTED`. No per-frame score is exposed, so the threshold setter is the only
  runtime sensitivity control.
* **[A]** 32 ms frames at 16 kHz (512 samples) are the right granularity. The code reads
  `get_samp_chunksize()`/`get_samp_rate()` at runtime instead of hardcoding them.
* **[V]** Source of the model files for the export script:
  `managed_components/espressif__esp-sr/model/wakenet_model/wn9_hiesp/`
  (contains `_MODEL_INFO_`, `wn9_data`, `wn9_index`). Re-verify the path after the
  component is fetched — the directory layout has changed between ESP-SR releases.
* **[A]** CPU: 4.3 ms of detection per 32 ms frame (~13% of one core) plus ~0.5 ms of
  I2S/PSRAM overhead. Needs a measurement on real hardware (P2).

### 3.3 Codebase

* **[V]** Boot order (`main/app_main.cpp`): `identity_init()` 68 → ctrl `init()` 72-76 →
  `user_app_init()` 78 → SD mount + `config_store_load()` 104-108 → `audio_ctrl::start()`
  171 → `display_ctrl::boot_kick_if_active()` 176.
* **[V]** `wake_ctrl::init()` belongs with the other `init()` calls (registers
  `cmd/wakeup`); `wake_ctrl::start()` belongs immediately after `audio_ctrl::start()`
  so the SD card is mounted and `config.json` is already parsed.
* **[V]** `audio_bsp_init()` is currently called from the audio task only
  (`audio_ctrl.cpp:39`) and is not idempotent. Two tasks calling it would double-init the
  codec, so the BSP must guard it.
* **[V]** With `reuse_dev = false` (`audio_bsp.c:26`) playback and capture are **two**
  `esp_codec_dev` handles (`codec_init.c:461-469`) wrapping **one** `es8311_codec` object
  and **one** I2S data interface. Closing playback powers the shared codec down while the
  record handle still believes it is open — the mic would then read silence or garbage.
  §5.3 fixes this by switching to `reuse_dev = true` (one handle, one `is_open` flag).
* **[V]** Publish/command conventions: `mqtt_register_cmd(topic, handler)` and
  `app::mqtt_publish(topic, payload, qos, retain)` (`status_ctrl.cpp:80,97`).
* **[V]** Config persistence convention: `config_store_save()` serializes each subsystem
  into `cJSON` and writes `/sdcard/config.json`; `config_store_load()` applies them
  (`config_store.cpp:14-106`).
* **[V]** The LED ring can be driven without touching saved state by calling
  `led_ctrl::handle_rgb_command()` with `"persist": false` (`led_ctrl.cpp:301,419-422`);
  a `duration` turns the ring off again on expiry (`led_ctrl.cpp:370-378,475`).
* **[V]** `i2s_music()`, `i2s_echo()`, `audio_play_init()`, `audio_playback_write()` in
  `audio_bsp.c` are unused dead code that duplicates the lifecycle this feature needs;
  they are removed in §5.3.

### 3.4 Product decisions encoded as defaults

* Ack sound filename defaults to empty (silent) until a sound is placed on the SD card;
  MQTT + LED still fire. Prevents a boot-time error on a fresh card.
* `wake.enabled` defaults to **true**.
* Re-trigger lockout of 1.5 s after a detection, so one utterance cannot fire repeatedly.
* Detection events are **not** persisted and are **not** retained on the MQTT topic
  (QoS 1, retain 0) — same rationale as `evt/status` (`status_ctrl.cpp:76-82`).

---

## 4. Architecture

### 4.1 Runtime flow

```
app_main
 ├─ wake_ctrl::init()                 defaults + cmd/wakeup registration
 ├─ SD mount → config_store_load()    applies wake.enabled / model / mode / threshold
 └─ wake_ctrl::start()                spawns "wake" task, core 0, prio 4, 8192 stack

wake task loop
 ├─ load model once (esp_srmodel_init("/sdcard/srmodel") + filter "hiesp")
 │    on failure: log once, retry every 60 s, never block boot
 ├─ loop:
 │    audio_lock(200 ms)
 │      audio_record_begin(16000, 1)      idempotent; PA forced OFF
 │      audio_record_read(frame)          1 frame = get_samp_chunksize() samples
 │    audio_unlock()
 │    wn->detect(md, frame)               CPU only, no lock held
 │    on WAKENET_DETECTED:
 │        wn->clean(md)                   avoid immediate re-trigger
 │        publish evt/wakeup (QoS 1)
 │        led_ctrl flash via cmd payload (persist:false)
 │        audio_ctrl::play(ack.wav)       audio task blocks on audio_lock
 │        1.5 s cooldown
```

### 4.2 Codec ownership

A single FreeRTOS mutex in `audio_bsp` plus a single `audio_session_t` is the whole
arbitration mechanism:

* the wake task holds the mutex for **one frame** at a time, so playback can interleave
  between frames with ≤32 ms latency;
* the audio task holds it for the whole file, so the mic is closed and PA-off while sound
  plays — this is what makes "no barge-in" free;
* `audio_record_begin()` is idempotent, so per-frame locking does not reopen the codec
  every 32 ms; it only reopens after a playback session closed it;
* `audio_playback_begin()` / `audio_record_begin()` each close whatever session was open
  before opening with their own sample format, so there is never a window where two
  callers believe they own the ES8311.

`reuse_dev = true` (`audio_bsp.c:26`) makes record and playback the *same*
`esp_codec_dev` handle, which removes the possibility of the two handles disagreeing
about the shared codec state — the root cause of the current breakage.

### 4.3 Detection response

| Action | Mechanism | Configurable |
| --- | --- | --- |
| MQTT event | `evt/wakeup`, JSON below, QoS 1, retain 0 | always on |
| LED flash | `led_ctrl::handle_rgb_command()` with `persist:false` | colour/brightness/duration |
| Ack sound | `audio_ctrl::play()` from `/sdcard/<name>` | `wake.ack_sound` |

```json
{"event":"wake","word":"Hi,ESP","model":"wn9_hiesp","channel":0,
 "threshold":0.635,"uptime_ms":84213,"level_dbfs":-28.4}
```

---

## 5. Change set

Files changed: 14 modified, 3 new. Files deliberately **not** touched are listed in §5.14.

### 5.1 `main/idf_component.yml`

```diff
 dependencies:
   ## Required IDF version
   idf:
     version: '>=4.1.0'
   lvgl/lvgl: ^9.3.0
   espressif/network_provisioning: ^1.2.4
   espressif/qrcode: ^0.2.0
   espressif/esp_codec_dev: ~1.3.4
+  espressif/esp-sr: ^2.5.5
```

### 5.2 `sdkconfig.defaults`

```diff
 CONFIG_CODEC_ES8311_SUPPORT=y
+
+# Always-on wake word ("Hi,ESP"): WakeNet9 model lives on the SD card, so no
+# `model` partition is needed and srmodels.bin is never flashed.
+CONFIG_MODEL_IN_SDCARD=y
+CONFIG_SR_WN_WN9_HIESP=y
```

> `CONFIG_SR_WN_WN9_HIESP` is the Kconfig symbol behind the `SR_WN_WN9_HIESP` entry
> ("Hi,ESP (wn9_hiesp)") in `esp-sr`'s `Kconfig`. Confirm the generated `CONFIG_` prefix
> from `build*/config/sdkconfig.h` after the first build. `CONFIG_AFE_INTERFACE_V1` is the
> default of its choice group and needs no entry.

### 5.3 `components/audio_bsp/audio_bsp.h` and `.c`

One handle, one mutex, symmetric begin/end pairs, dead code removed, PA under our control.

```diff
--- a/components/audio_bsp/audio_bsp.h
+++ b/components/audio_bsp/audio_bsp.h
@@
 #ifdef __cplusplus
 extern "C" {
 #endif
 
+#include <stdbool.h>
+#include <stdint.h>
+
 void audio_bsp_init(void);
-void i2s_music(void *args);
-void i2s_echo(void *arg);
 void audio_playback_set_vol(uint8_t vol);
-uint8_t *i2s_get_handle(uint32_t *len);
-
-void audio_play_init(void);
-
-void audio_playback_read(void *data_ptr,uint32_t len);
-
-void audio_playback_write(void *data_ptr,uint32_t len);
+
+bool audio_lock(uint32_t timeout_ms);
+void audio_unlock(void);
+
+bool audio_record_begin(uint32_t sample_rate, uint8_t channel);
+int  audio_record_read(void *data, uint32_t len);
+void audio_record_end(void);
+
+bool audio_playback_begin(uint32_t sample_rate, uint8_t channel);
+int  audio_playback_write(void *data, uint32_t len);
+void audio_playback_end(void);
+
+void audio_pa_set(bool on);
 
 #ifdef __cplusplus
 }
 #endif
```

```diff
--- a/components/audio_bsp/audio_bsp.c
+++ b/components/audio_bsp/audio_bsp.c
@@
 #include "esp_codec_dev.h"
 #include "esp_heap_caps.h"
+#include "driver/gpio.h"
+#include "freertos/semphr.h"
+#include "user_config.h"
 
-
-esp_codec_dev_handle_t playback = NULL;
-esp_codec_dev_handle_t record = NULL;
-
-
-extern const uint8_t music_pcm_start[] asm("_binary_canon_pcm_start");
-extern const uint8_t music_pcm_end[]   asm("_binary_canon_pcm_end");
+static const char *TAG = "audio_bsp";
+
+typedef enum {
+	SESSION_NONE = 0,
+	SESSION_RECORD,
+	SESSION_PLAYBACK,
+} audio_session_t;
+
+static esp_codec_dev_handle_t s_codec = NULL;
+static SemaphoreHandle_t s_codec_lock = NULL;
+static bool s_inited = false;
+static audio_session_t s_session = SESSION_NONE;
@@
 void audio_bsp_init(void)
 {
-  	set_codec_board_type("S3_ePaper_1_54");
+	if (s_inited) {
+		return;
+	}
+	set_codec_board_type("S3_ePaper_1_54");
 	codec_init_cfg_t codec_cfg = 
     {
         .in_mode = CODEC_I2S_MODE_STD,
         .out_mode = CODEC_I2S_MODE_STD,
         .in_use_tdm = false,
-        .reuse_dev = false,
+        .reuse_dev = true,
     };
   	ESP_ERROR_CHECK(init_codec(&codec_cfg));
-  	playback = get_playback_handle();
-  	record = get_record_handle();
+	s_codec = get_playback_handle();
+	s_codec_lock = xSemaphoreCreateMutex();
+	s_inited = true;
+	ESP_LOGI(TAG, "codec ready (single shared handle: %p)", s_codec);
 }
```

The four dead/duplicate helpers (`i2s_music`, `i2s_echo`, `audio_play_init`,
`audio_playback_read`, `audio_playback_write`, `i2s_get_handle`) are deleted; the only
caller of the record path, `audio_playback_read()`, has none today (§3.3).

New implementation body (continues the state block above):

```c
bool audio_lock(uint32_t timeout_ms)
{
	return s_codec_lock != NULL &&
		   xSemaphoreTake(s_codec_lock, pdMS_TO_TICKS(timeout_ms)) == pdTRUE;
}

void audio_unlock(void)
{
	if (s_codec_lock != NULL) {
		xSemaphoreGive(s_codec_lock);
	}
}

void audio_pa_set(bool on)
{
	gpio_set_level(AUDIO_PA_PIN, on ? 1 : 0);
}

static bool open_codec(uint32_t sample_rate, uint8_t channel)
{
	esp_codec_dev_sample_info_t fs = {
		.sample_rate = sample_rate,
		.channel = channel,
		.bits_per_sample = 16,
	};
	if (s_codec == NULL) {
		return false;
	}
	if (esp_codec_dev_open(s_codec, &fs) != ESP_CODEC_DEV_OK) {
		ESP_LOGE(TAG, "esp_codec_dev_open(%u Hz, %u ch) failed", sample_rate, channel);
		return false;
	}
	return true;
}

static void close_codec(void)
{
	if (s_session == SESSION_NONE) {
		return;
	}
	esp_codec_dev_close(s_codec);
	s_session = SESSION_NONE;
	audio_pa_set(false);
}

bool audio_record_begin(uint32_t sample_rate, uint8_t channel)
{
	if (s_session == SESSION_RECORD) {
		return true;
	}
	close_codec();
	if (!open_codec(sample_rate, channel)) {
		return false;
	}
	s_session = SESSION_RECORD;
	esp_codec_dev_set_in_gain(s_codec, 30.0);
	audio_pa_set(false);
	return true;
}

int audio_record_read(void *data, uint32_t len)
{
	if (s_session != SESSION_RECORD) {
		return -1;
	}
	return esp_codec_dev_read(s_codec, data, len) == ESP_CODEC_DEV_OK ? (int)len : -1;
}

void audio_record_end(void)
{
	close_codec();
}

bool audio_playback_begin(uint32_t sample_rate, uint8_t channel)
{
	if (s_session == SESSION_PLAYBACK) {
		return true;
	}
	close_codec();
	if (!open_codec(sample_rate, channel)) {
		return false;
	}
	s_session = SESSION_PLAYBACK;
	audio_pa_set(true);
	return true;
}

int audio_playback_write(void *data, uint32_t len)
{
	if (s_session != SESSION_PLAYBACK) {
		return -1;
	}
	return esp_codec_dev_write(s_codec, data, len) == ESP_CODEC_DEV_OK ? (int)len : -1;
}

void audio_playback_end(void)
{
	close_codec();
}

void audio_playback_set_vol(uint8_t vol)
{
	if (s_codec != NULL) {
		esp_codec_dev_set_out_vol(s_codec, (float)vol);
	}
}
```

> One `s_session` enum instead of two booleans, because the ES8311 and the I2S channel are
> shared: there can only ever be one open session, and **any** close invalidates **any**
> open. `audio_playback_begin()` and `audio_record_begin()` therefore close first and
> reopen with the sample format their caller needs — that transition is what makes the
> mic go quiet and then come back after a sound finishes. This invariant is exactly what
> the old two-handle setup violated (`codec_init.c:461-469` + `audio_ctrl.cpp:86,108`).

### 5.4 `main/user_config.h`

```diff
 #define Audio_PWR_PIN GPIO_NUM_42
 #define VBAT_PWR_PIN GPIO_NUM_17
+
+/* Speaker amplifier enable driven by the ES8311 codec (components/codec_board/board_cfg.txt) */
+#define AUDIO_PA_PIN GPIO_NUM_46
```

### 5.5 `main/audio_ctrl.hpp` / `audio_ctrl.cpp`

The playback task now goes through the BSP session API and holds the codec lock for the
whole file, which is what pauses the microphone. A `play()` entry point lets the wake task
request the ack sound without going through MQTT.

```diff
--- a/main/audio_ctrl.hpp
+++ b/main/audio_ctrl.hpp
@@
 #pragma once
 
+#include <cstdint>
 #include <string>
@@
 // Download completion handler (registered for DownloadTarget::AUDIO).
 void notify_downloaded(bool success, const std::string &filepath);
+
+void play(const char *filename, uint8_t volume);
 
 } // namespace audio_ctrl
```

```diff
--- a/main/audio_ctrl.cpp
+++ b/main/audio_ctrl.cpp
@@
 	audio_bsp_init();
-	esp_codec_dev_sample_info_t fs = {};
-	fs.sample_rate = 16000;
-	fs.channel = 2;
-	fs.bits_per_sample = 16;
-	esp_codec_dev_handle_t playback = get_playback_handle();
@@
 		ESP_LOGI(TAG, "Audio play: %s (vol=%d)", filename, volume);
-		esp_codec_dev_set_out_vol(playback, (float)volume);
 
 		if (strcmp(filename, "boot") == 0)
 		{
 			extern const uint8_t music_pcm_start[] asm("_binary_canon_pcm_start");
 			extern const uint8_t music_pcm_end[]   asm("_binary_canon_pcm_end");
 			size_t pcm_size = music_pcm_end - music_pcm_start;
 			uint8_t *pcm_ptr = (uint8_t *)music_pcm_start;
 
-			if (esp_codec_dev_open(playback, &fs) == ESP_CODEC_DEV_OK)
+			if (!audio_lock(1000))
+			{
+				ESP_LOGE(TAG, "Audio: codec busy, dropping playback");
+				continue;
+			}
+			if (audio_playback_begin(16000, 2))
 			{
+				audio_playback_set_vol(volume);
 				size_t written = 0;
 				while (written < pcm_size)
 				{
-					esp_codec_dev_write(playback, pcm_ptr + written, 256);
+					audio_playback_write(pcm_ptr + written, 256);
 					written += 256;
 				}
+				audio_playback_end();
 			}
-			esp_codec_dev_close(playback);
+			audio_unlock();
 			ESP_LOGI(TAG, "Boot sound playback complete");
 		}
 		else
@@
-			if (esp_codec_dev_open(playback, &fs) == ESP_CODEC_DEV_OK)
+			if (!audio_lock(1000))
+			{
+				ESP_LOGE(TAG, "Audio: codec busy, dropping %s", filename);
+				fclose(f);
+				continue;
+			}
+			if (audio_playback_begin(16000, 2))
 			{
+				audio_playback_set_vol(volume);
 				uint8_t buf[1024];
 				size_t bytes_read;
 				while ((bytes_read = fread(buf, 1, sizeof(buf), f)) > 0)
 				{
-					esp_codec_dev_write(playback, buf, bytes_read);
+					audio_playback_write(buf, bytes_read);
 				}
+				audio_playback_end();
 			}
-			esp_codec_dev_close(playback);
+			audio_unlock();
 			fclose(f);
 			ESP_LOGI(TAG, "Audio file playback complete: %s", file_path.c_str());
 		}
 	}
 }
+
+void audio_ctrl::play(const char *filename, uint8_t volume)
+{
+	if (filename == NULL || filename[0] == '\0') {
+		return;
+	}
+	{
+		std::lock_guard<std::mutex> lock(s_state.mutex);
+		strncpy(s_state.filename, filename, sizeof(s_state.filename) - 1);
+		s_state.filename[sizeof(s_state.filename) - 1] = '\0';
+		s_state.volume = volume;
+		s_state.active = true;
+	}
+	if (s_audio_task_handle != NULL) {
+		xTaskNotifyGive(s_audio_task_handle);
+	}
+}
```

The duplicated filename/volume/notify block in `handle_command()` and
`notify_downloaded()` collapses into `play()` as a follow-up cleanup (not required for
this feature). After this change `#include "codec_init.h"` in `audio_ctrl.cpp` is unused
and can go; `audio_bsp.h` is the only audio include left.

### 5.6 `main/wake_ctrl.hpp` (new)

```cpp
#pragma once

#include <cstdint>

#include "cJSON.h"

// Always-on wake-word subsystem: owns the ESP-SR WakeNet9 model, streams the
// ES8311 microphone through it, and reacts to detections.

namespace wake_ctrl {

void init(void);
void start(void);
void stop(void);

void handle_command(const char *payload);

void status_serialize(cJSON *obj);
void status_apply(cJSON *obj);

bool listening(void);
const char *model_name_get(void);
float threshold_get(void);

} // namespace wake_ctrl
```

### 5.7 `main/wake_ctrl.cpp` (new)

```cpp
#include <cmath>
#include <cstdio>
#include <cstdlib>
#include <cstring>

#include "freertos/FreeRTOS.h"
#include "freertos/task.h"

#include "esp_log.h"
#include "esp_timer.h"

#include "cJSON.h"

#include "model_path.h"
#include "esp_wn_iface.h"
#include "esp_wn_models.h"

#include "audio_bsp.h"
#include "audio_ctrl.hpp"
#include "app_common.hpp"
#include "config_store.hpp"
#include "identity.hpp"
#include "led_ctrl.hpp"
#include "mqtt_io.hpp"
#include "wake_ctrl.hpp"

static const char *TAG = "wake";

static const char *SR_MODEL_PATH = "/sdcard/srmodel";
static const uint32_t MODEL_RETRY_MS   = 60000;
static const uint32_t COOLDOWN_MS      = 1500;
static const uint32_t FRAME_TIMEOUT_MS = 200;

static struct {
	bool enabled;
	char model[32];
	char mode[16];
	float threshold;
	char ack_sound[64];
	uint8_t ack_volume;
	char led_color[16];
	uint8_t led_brightness;
	uint16_t led_duration_s;
	bool listening;
} s_wake = {
	.enabled = true,
	.model = "hiesp",
	.mode = "3ch95",
	.threshold = 0.635f,
	.ack_sound = "",
	.ack_volume = 70,
	.led_color = "#00E5FF",
	.led_brightness = 60,
	.led_duration_s = 2,
	.listening = false,
};

static srmodel_list_t *s_models = NULL;
static esp_wn_iface_t *s_wn = NULL;
static model_iface_data_t *s_md = NULL;
static int16_t *s_mono = NULL;
static int16_t *s_frame = NULL;
static int s_chunk = 512;
static int s_channels = 1;
static int s_rate = 16000;
static volatile bool s_reload = false;
static TaskHandle_t s_task = NULL;

static det_mode_t mode_from_string(const char *mode)
{
	if (strcmp(mode, "3ch90") == 0) return DET_MODE_3CH_90;
	if (strcmp(mode, "2ch95") == 0) return DET_MODE_2CH_95;
	if (strcmp(mode, "2ch90") == 0) return DET_MODE_2CH_90;
	if (strcmp(mode, "95")    == 0) return DET_MODE_95;
	return DET_MODE_3CH_95;
}

static float clampf(float value, float lo, float hi)
{
	return value < lo ? lo : (value > hi ? hi : value);
}

static float rms_dbfs(const int16_t *samples, int count)
{
	double acc = 0.0;
	for (int i = 0; i < count; i++) {
		double v = samples[i] / 32768.0;
		acc += v * v;
	}
	double rms = sqrt(acc / (count > 0 ? count : 1));
	return rms > 0.0 ? (float)(20.0 * log10(rms)) : -99.0f;
}

static void model_release(void)
{
	if (s_wn != NULL && s_md != NULL) {
		s_wn->destroy(s_md);
	}
	s_md = NULL;
	s_wn = NULL;
	if (s_models != NULL) {
		esp_srmodel_deinit(s_models);
		s_models = NULL;
	}
	free(s_mono);
	free(s_frame);
	s_mono = NULL;
	s_frame = NULL;
	s_wake.listening = false;
}

static bool model_load(void)
{
	srmodel_list_t *models = esp_srmodel_init(SR_MODEL_PATH);
	if (models == NULL) {
		ESP_LOGE(TAG, "no models under %s", SR_MODEL_PATH);
		return false;
	}
	char *name = esp_srmodel_filter(models, ESP_WN_PREFIX, s_wake.model);
	if (name == NULL) {
		ESP_LOGE(TAG, "no wake word matching '%s'", s_wake.model);
		esp_srmodel_deinit(models);
		return false;
	}
	esp_wn_iface_t *wn = esp_wn_handle_from_name(name);
	if (wn == NULL) {
		esp_srmodel_deinit(models);
		return false;
	}
	model_iface_data_t *md = wn->create(name, mode_from_string(s_wake.mode));
	if (md == NULL) {
		ESP_LOGE(TAG, "create(%s, %s) failed", name, s_wake.mode);
		esp_srmodel_deinit(models);
		return false;
	}

	s_chunk = wn->get_samp_chunksize(md);
	s_rate = wn->get_samp_rate(md);
	s_channels = wn->get_channel_num(md);
	s_mono = (int16_t *)calloc(s_chunk, sizeof(int16_t));
	s_frame = (int16_t *)calloc(s_chunk * s_channels, sizeof(int16_t));
	if (s_mono == NULL || s_frame == NULL) {
		model_release();
		return false;
	}

	int words = wn->get_word_num(md);
	for (int i = 1; i <= words; i++) {
		char *word = wn->get_word_name(md, i);
		ESP_LOGI(TAG, "word[%d] = %s", i, word != NULL ? word : "?");
	}
	wn->set_det_threshold(md, s_wake.threshold, 1);

	s_models = models;
	s_wn = wn;
	s_md = md;

	ESP_LOGI(TAG, "ready: model=%s rate=%d chunk=%d channels=%d words=%d thr=%.3f",
			 name, s_rate, s_chunk, s_channels, words, s_wake.threshold);
	return true;
}

static void publish_detection(int channel, float level_dbfs)
{
	cJSON *root = cJSON_CreateObject();
	if (root == NULL) {
		return;
	}
	cJSON_AddStringToObject(root, "event", "wake");
	cJSON_AddStringToObject(root, "word", "Hi,ESP");
	cJSON_AddStringToObject(root, "model", s_wake.model);
	cJSON_AddNumberToObject(root, "channel", channel);
	cJSON_AddNumberToObject(root, "threshold", s_wake.threshold);
	cJSON_AddNumberToObject(root, "level_dbfs", level_dbfs);
	cJSON_AddNumberToObject(root, "uptime_ms", (double)(esp_timer_get_time() / 1000));

	char *payload = cJSON_PrintUnformatted(root);
	if (payload != NULL) {
		app::mqtt_publish(identity_topic_evt_wakeup(), payload, 1, 0);
		free(payload);
	}
	cJSON_Delete(root);
}

static void led_flash(void)
{
	char payload[192];
	snprintf(payload, sizeof(payload),
			 "{\"enable\":true,\"pattern\":\"solid_color\",\"color\":\"%s\","
			 "\"brightness\":%u,\"duration\":%u,\"persist\":false}",
			 s_wake.led_color, s_wake.led_brightness, s_wake.led_duration_s);
	led_ctrl::handle_rgb_command(payload);
}

static void wake_task(void *arg)
{
	audio_bsp_init();
	vTaskDelay(pdMS_TO_TICKS(500));

	int64_t retry_at = 0;
	uint32_t frames = 0;

	for (;;)
	{
		if (s_reload) {
			s_reload = false;
			if (audio_lock(FRAME_TIMEOUT_MS)) {
				audio_record_end();
				audio_unlock();
			}
			model_release();
			retry_at = 0;
		}

		if (!s_wake.enabled) {
			s_wake.listening = false;
			vTaskDelay(pdMS_TO_TICKS(500));
			continue;
		}

		if (s_wn == NULL) {
			int64_t now = esp_timer_get_time() / 1000;
			if (now < retry_at) {
				vTaskDelay(pdMS_TO_TICKS(500));
				continue;
			}
			retry_at = now + MODEL_RETRY_MS;
			if (!model_load()) {
				continue;
			}
		}
		s_wake.listening = true;

		if (!audio_lock(FRAME_TIMEOUT_MS)) {
			continue;
		}
		int bytes = -1;
		if (audio_record_begin(s_rate, 1)) {
			bytes = audio_record_read(s_mono, s_chunk * sizeof(int16_t));
		}
		audio_unlock();

		if (bytes < 0) {
			vTaskDelay(pdMS_TO_TICKS(20));
			continue;
		}

		if (s_channels == 1) {
			memcpy(s_frame, s_mono, s_chunk * sizeof(int16_t));
		} else {
			for (int i = 0; i < s_chunk; i++) {
				for (int c = 0; c < s_channels; c++) {
					s_frame[(i * s_channels) + c] = s_mono[i];
				}
			}
		}

		wakenet_state_t state = s_wn->detect(s_md, s_frame);
		float level = rms_dbfs(s_mono, s_chunk);

		if (++frames % 50 == 0) {
			ESP_LOGD(TAG, "listening, level=%.1f dBFS", level);
		}
		if (state != WAKENET_DETECTED) {
			continue;
		}

		int channel = s_wn->get_triggered_channel(s_md);
		s_wn->clean(s_md);
		ESP_LOGI(TAG, "WAKE 'Hi,ESP' ch=%d level=%.1f dBFS", channel, level);

		publish_detection(channel, level);
		led_flash();
		audio_ctrl::play(s_wake.ack_sound, s_wake.ack_volume);

		vTaskDelay(pdMS_TO_TICKS(COOLDOWN_MS));
	}
}

void wake_ctrl::init(void)
{
	mqtt_register_cmd(identity_topic_cmd_wakeup(), wake_ctrl::handle_command);
}

void wake_ctrl::start(void)
{
	if (s_task == NULL) {
		xTaskCreatePinnedToCore(wake_task, "wake", 8192, NULL, 4, &s_task, 0);
	}
}

void wake_ctrl::stop(void)
{
	if (s_task != NULL) {
		vTaskDelete(s_task);
		s_task = NULL;
		s_wake.enabled = false;
	}
}

void wake_ctrl::handle_command(const char *payload)
{
	ESP_LOGI(TAG, "Wake command received");

	cJSON *json = cJSON_Parse(payload);
	if (json == NULL) {
		ESP_LOGE(TAG, "Wake: invalid JSON");
		return;
	}

	bool reload = false;

	cJSON *enabled = cJSON_GetObjectItemCaseSensitive(json, "enabled");
	if (cJSON_IsBool(enabled)) {
		s_wake.enabled = cJSON_IsTrue(enabled);
	}

	cJSON *model = cJSON_GetObjectItemCaseSensitive(json, "model");
	if (cJSON_IsString(model) && model->valuestring != NULL) {
		if (strcmp(s_wake.model, model->valuestring) != 0) {
			strncpy(s_wake.model, model->valuestring, sizeof(s_wake.model) - 1);
			s_wake.model[sizeof(s_wake.model) - 1] = '\0';
			reload = true;
		}
	}

	cJSON *mode = cJSON_GetObjectItemCaseSensitive(json, "mode");
	if (cJSON_IsString(mode) && mode->valuestring != NULL) {
		if (strcmp(s_wake.mode, mode->valuestring) != 0) {
			strncpy(s_wake.mode, mode->valuestring, sizeof(s_wake.mode) - 1);
			s_wake.mode[sizeof(s_wake.mode) - 1] = '\0';
			reload = true;
		}
	}

	cJSON *threshold = cJSON_GetObjectItemCaseSensitive(json, "threshold");
	if (cJSON_IsNumber(threshold)) {
		float value = clampf((float)threshold->valuedouble, 0.4f, 0.9999f);
		if (value != s_wake.threshold) {
			s_wake.threshold = value;
			reload = true;
		}
	}

	cJSON *ack = cJSON_GetObjectItemCaseSensitive(json, "ack_sound");
	if (cJSON_IsString(ack) && ack->valuestring != NULL) {
		strncpy(s_wake.ack_sound, ack->valuestring, sizeof(s_wake.ack_sound) - 1);
		s_wake.ack_sound[sizeof(s_wake.ack_sound) - 1] = '\0';
	}

	cJSON *ack_volume = cJSON_GetObjectItemCaseSensitive(json, "ack_volume");
	if (cJSON_IsNumber(ack_volume)) {
		s_wake.ack_volume = (uint8_t)clampf((float)ack_volume->valuedouble, 0.0f, 100.0f);
	}

	cJSON *led_color = cJSON_GetObjectItemCaseSensitive(json, "led_color");
	if (cJSON_IsString(led_color) && led_color->valuestring != NULL) {
		strncpy(s_wake.led_color, led_color->valuestring, sizeof(s_wake.led_color) - 1);
		s_wake.led_color[sizeof(s_wake.led_color) - 1] = '\0';
	}

	cJSON *led_brightness = cJSON_GetObjectItemCaseSensitive(json, "led_brightness");
	if (cJSON_IsNumber(led_brightness)) {
		s_wake.led_brightness = (uint8_t)clampf((float)led_brightness->valuedouble, 0.0f, 100.0f);
	}

	cJSON *led_duration = cJSON_GetObjectItemCaseSensitive(json, "led_duration_s");
	if (cJSON_IsNumber(led_duration)) {
		s_wake.led_duration_s = (uint16_t)clampf((float)led_duration->valuedouble, 0.0f, 3600.0f);
	}

	cJSON_Delete(json);

	if (reload) {
		s_reload = true;
	}
	config_store_save();
}

void wake_ctrl::status_serialize(cJSON *obj)
{
	cJSON_AddBoolToObject(obj, "enabled", s_wake.enabled);
	cJSON_AddStringToObject(obj, "model", s_wake.model);
	cJSON_AddStringToObject(obj, "mode", s_wake.mode);
	cJSON_AddNumberToObject(obj, "threshold", s_wake.threshold);
	cJSON_AddStringToObject(obj, "ack_sound", s_wake.ack_sound);
	cJSON_AddNumberToObject(obj, "ack_volume", s_wake.ack_volume);
	cJSON_AddStringToObject(obj, "led_color", s_wake.led_color);
	cJSON_AddNumberToObject(obj, "led_brightness", s_wake.led_brightness);
	cJSON_AddNumberToObject(obj, "led_duration_s", s_wake.led_duration_s);
	cJSON_AddBoolToObject(obj, "listening", s_wake.listening);
}

void wake_ctrl::status_apply(cJSON *obj)
{
	cJSON *enabled = cJSON_GetObjectItemCaseSensitive(obj, "enabled");
	if (cJSON_IsBool(enabled)) {
		s_wake.enabled = cJSON_IsTrue(enabled);
	}

	cJSON *model = cJSON_GetObjectItemCaseSensitive(obj, "model");
	if (cJSON_IsString(model) && model->valuestring != NULL) {
		strncpy(s_wake.model, model->valuestring, sizeof(s_wake.model) - 1);
		s_wake.model[sizeof(s_wake.model) - 1] = '\0';
	}

	cJSON *mode = cJSON_GetObjectItemCaseSensitive(obj, "mode");
	if (cJSON_IsString(mode) && mode->valuestring != NULL) {
		strncpy(s_wake.mode, mode->valuestring, sizeof(s_wake.mode) - 1);
		s_wake.mode[sizeof(s_wake.mode) - 1] = '\0';
	}

	cJSON *threshold = cJSON_GetObjectItemCaseSensitive(obj, "threshold");
	if (cJSON_IsNumber(threshold)) {
		s_wake.threshold = clampf((float)threshold->valuedouble, 0.4f, 0.9999f);
	}

	cJSON *ack = cJSON_GetObjectItemCaseSensitive(obj, "ack_sound");
	if (cJSON_IsString(ack) && ack->valuestring != NULL) {
		strncpy(s_wake.ack_sound, ack->valuestring, sizeof(s_wake.ack_sound) - 1);
		s_wake.ack_sound[sizeof(s_wake.ack_sound) - 1] = '\0';
	}

	cJSON *ack_volume = cJSON_GetObjectItemCaseSensitive(obj, "ack_volume");
	if (cJSON_IsNumber(ack_volume)) {
		s_wake.ack_volume = (uint8_t)clampf((float)ack_volume->valuedouble, 0.0f, 100.0f);
	}

	cJSON *led_color = cJSON_GetObjectItemCaseSensitive(obj, "led_color");
	if (cJSON_IsString(led_color) && led_color->valuestring != NULL) {
		strncpy(s_wake.led_color, led_color->valuestring, sizeof(s_wake.led_color) - 1);
		s_wake.led_color[sizeof(s_wake.led_color) - 1] = '\0';
	}

	cJSON *led_brightness = cJSON_GetObjectItemCaseSensitive(obj, "led_brightness");
	if (cJSON_IsNumber(led_brightness)) {
		s_wake.led_brightness = (uint8_t)clampf((float)led_brightness->valuedouble, 0.0f, 100.0f);
	}

	cJSON *led_duration = cJSON_GetObjectItemCaseSensitive(obj, "led_duration_s");
	if (cJSON_IsNumber(led_duration)) {
		s_wake.led_duration_s = (uint16_t)clampf((float)led_duration->valuedouble, 0.0f, 3600.0f);
	}

	ESP_LOGI(TAG, "Restored wake config: enabled=%d model=%s mode=%s thr=%.3f",
			 s_wake.enabled, s_wake.model, s_wake.mode, s_wake.threshold);
}

bool wake_ctrl::listening(void)
{
	return s_wake.listening;
}

const char *wake_ctrl::model_name_get(void)
{
	return s_wake.model;
}

float wake_ctrl::threshold_get(void)
{
	return s_wake.threshold;
}
```

Notes on this module:

* The capture buffer is allocated from the size the model asks for
  (`get_samp_chunksize()` × `get_channel_num()`), so nothing is hardcoded.
* `s_channels > 1` duplicates the single microphone channel into an interleaved buffer.
  That branch is the OQ-1 resolution point: if P1 shows the model wants real multiple
  channels, create it with `DET_MODE_95` (`s_channels == 1`) instead.
* `detect()` runs **outside** the codec lock — it is pure CPU, so playback is never
  delayed by detection.
* `s_reload` is how a `cmd/wakeup` change to `model`, `mode` or `threshold` takes effect
  without a reboot; the next `threshold`-only change also needs a reload because
  `set_det_threshold()` is applied at create time.

### 5.8 `main/CMakeLists.txt`

```diff
 idf_component_register(SRCS "app_common.cpp" "app_main.cpp" "audio_ctrl.cpp" "config_store.cpp"
                     "display_ctrl.cpp" "download_mgr.cpp" "identity.cpp" "led_ctrl.cpp"
                     "mqtt_io.cpp" "ota_ctrl.cpp" "provisioning.cpp" "rgb_color.cpp"
-                    "status_ctrl.cpp" "ui_port.cpp" "data_downloader.cpp" "wifi.c" "wifi_no.c"
+                    "status_ctrl.cpp" "ui_port.cpp" "data_downloader.cpp" "wake_ctrl.cpp" "wifi.c" "wifi_no.c"
                     INCLUDE_DIRS "./"
                     REQUIRES led_strip sdcard_manager esp_http_client user_app nvs_flash mqtt json mqtt_logger audio_bsp app_update esp_app_format network_provisioning qrcode esp_timer esp_wifi esp_netif esp_event
-                    PRIV_REQUIRES codec_board
+                    PRIV_REQUIRES codec_board espressif__esp-sr
 )
```

### 5.9 `main/app_main.cpp`

```diff
 #include "status_ctrl.hpp"
 #include "ui_port.hpp"
+#include "wake_ctrl.hpp"
@@
 	ota_ctrl::init();
 	status_ctrl::init();
+	wake_ctrl::init();
@@
 	xTaskCreate(ui_overlay_task, "ui_overlay", 4096, NULL, 4, NULL);
 	audio_ctrl::start();
+	// After the SD mount (model + ack sound live there) and after the audio task
+	// owns its side of the shared codec.
+	wake_ctrl::start();
```

### 5.10 `main/identity.hpp` / `identity.cpp`

```diff
--- a/main/identity.hpp
+++ b/main/identity.hpp
@@
 const char *identity_topic_evt_status(void);
+const char *identity_topic_cmd_wakeup(void);
+const char *identity_topic_evt_wakeup(void);
```

```diff
--- a/main/identity.cpp
+++ b/main/identity.cpp
@@
 static char s_mqtt_evt_status_topic[MQTT_TOPIC_MAX_LEN];
+static char s_mqtt_evt_wakeup_topic[MQTT_TOPIC_MAX_LEN];
+static char s_mqtt_cmd_wakeup_topic[MQTT_TOPIC_MAX_LEN];
@@
 	snprintf(s_mqtt_evt_status_topic, sizeof(s_mqtt_evt_status_topic),
 			 "thelink/%s/evt/status", s_device_id);
+	snprintf(s_mqtt_evt_wakeup_topic, sizeof(s_mqtt_evt_wakeup_topic),
+			 "thelink/%s/evt/wakeup", s_device_id);
+	snprintf(s_mqtt_cmd_wakeup_topic, sizeof(s_mqtt_cmd_wakeup_topic),
+			 "thelink/%s/cmd/wakeup", s_device_id);
@@
 	ESP_LOGI("DEVICE", "Status evt topic: %s", s_mqtt_evt_status_topic);
+	ESP_LOGI("DEVICE", "Wake cmd topic: %s", s_mqtt_cmd_wakeup_topic);
+	ESP_LOGI("DEVICE", "Wake evt topic: %s", s_mqtt_evt_wakeup_topic);
@@
 const char *identity_topic_evt_status(void)
 {
 	return s_mqtt_evt_status_topic;
 }
+
+const char *identity_topic_evt_wakeup(void)
+{
+	return s_mqtt_evt_wakeup_topic;
+}
+
+const char *identity_topic_cmd_wakeup(void)
+{
+	return s_mqtt_cmd_wakeup_topic;
+}
```

### 5.11 `main/config_store.cpp` and `main/status_ctrl.cpp`

```diff
--- a/main/config_store.cpp
+++ b/main/config_store.cpp
@@
 #include "led_ctrl.hpp"
+#include "wake_ctrl.hpp"
@@
 	// Add LED pattern state as a structured object
 	{
 		cJSON *led = cJSON_CreateObject();
 		led_ctrl::status_serialize(led);
 		cJSON_AddItemToObject(root, "led", led);
 	}
+
+	// Add wake-word configuration
+	{
+		cJSON *wake = cJSON_CreateObject();
+		wake_ctrl::status_serialize(wake);
+		cJSON_AddItemToObject(root, "wake", wake);
+	}
@@
 			// Parse and apply LED notification parameters
 			cJSON *led_item = cJSON_GetObjectItemCaseSensitive(json, "led");
@@
 			}
+
+			// Parse and apply wake-word parameters
+			cJSON *wake_item = cJSON_GetObjectItemCaseSensitive(json, "wake");
+			if (cJSON_IsObject(wake_item))
+			{
+				wake_ctrl::status_apply(wake_item);
+			}
```

`wake_ctrl::status_serialize()` emits `enabled`, `model`, `mode`, `threshold`,
`ack_sound`, `ack_volume`, `led_color`, `led_brightness`, `led_duration_s` and
`listening`; `status_apply()` accepts the same keys except `listening`, which is a
transient runtime field — the value `config_store_save()` happens to write into
`config.json` is never applied back. The wake task never calls `config_store_save()`.

```diff
--- a/main/status_ctrl.cpp
+++ b/main/status_ctrl.cpp
@@
 #include "status_ctrl.hpp"
+#include "wake_ctrl.hpp"
@@
 	cJSON_AddStringToObject(root, "rgb_pattern", led_ctrl::pattern_get());
+
+	{
+		cJSON *wake = cJSON_CreateObject();
+		wake_ctrl::status_serialize(wake);
+		cJSON_AddItemToObject(root, "wake", wake);
+	}
```

### 5.12 `scripts/export_wake_model.py` (new)

Copies the bundled model to the SD card and prints the verification checklist.

```python
#!/usr/bin/env python3
"""Copy a bundled ESP-SR wake-word model from managed_components onto the SD card."""

import argparse
import shutil
import sys
from pathlib import Path

MODEL_SUBDIR = Path("model/wakenet_model")

def find_component_root(project: Path) -> Path:
    candidates = [
        project / "managed_components" / "espressif__esp-sr",
        project / "components" / "esp-sr",
    ]
    for candidate in candidates:
        if (candidate / MODEL_SUBDIR).is_dir():
            return candidate
    raise SystemExit("esp-sr component not found; run idf.py reconfigure first")

def main() -> int:
    parser = argparse.ArgumentParser()
    parser.add_argument("--model", default="wn9_hiesp")
    parser.add_argument("--out", default="/media/$USER/thelink/srmodel")
    parser.add_argument("--project", default=str(Path(__file__).resolve().parent.parent))
    args = parser.parse_args()

    src = find_component_root(Path(args.project)) / MODEL_SUBDIR / args.model
    if not src.is_dir():
        raise SystemExit(f"model {args.model} not found at {src}")

    dst = Path(args.out) / args.model
    dst.mkdir(parents=True, exist_ok=True)
    for name in ("_MODEL_INFO_", "wn9_data", "wn9_index"):
        shutil.copy2(src / name, dst / name)
        print(f"{src / name} -> {dst / name}")

    print("\nVerify the card contains:")
    print(f"  {args.out}/wn9_hiesp/_MODEL_INFO_")
    print(f"  {args.out}/wn9_hiesp/wn9_data")
    print(f"  {args.out}/wn9_hiesp/wn9_index")
    return 0

if __name__ == "__main__":
    sys.exit(main())
```

### 5.13 `Readme.md`

```diff
-- microphone (available for future projects)
+- microphone (always-on wake word "Hi,ESP" — see [feature_wake.md](feature_wake.md))
```

### 5.14 Deliberately not touched

* `partitions.csv`, `partitions_dev.csv` — the model is on the SD card, and
  `esp-sr/CMakeLists.txt` skips model flashing when no `model` partition exists (§3.2).
* `scripts/flash_all.py` — nothing new is written to flash.
* `sdkconfig.prod`, `scripts/build.py` — both profiles get the feature; no per-profile
  difference.
* `components/board_power_bsp` — the audio rail is already enabled at boot
  (`user_app.cpp:26`); power management is §8, not this feature.
* `main/audio_ctrl.cpp` cleanup of the duplicated play-state blocks (deferred).

---

## 6. Phases and verification

| Phase | Work | Done when |
| --- | --- | --- |
| **P0** | Land the §5.3 BSP rework (single handle, session enum, PA control, idempotent init), then probe the mic: log RMS dBFS every 500 ms | dBFS in a sane range at 0.3 m; PA stays silent while listening; `audio_pa_set(false)` is what keeps it quiet; the boot sound still plays |
| **P1** | Add ESP-SR, export the model, load it, log `get_samp_chunksize()`, `get_channel_num()`, `get_samp_rate()`, `get_word_num()` | model loads from `/sdcard/srmodel`; word list shows `Hi,ESP`; removing the model directory produces a warning + 60 s retry, not a boot loop |
| **P2** | Feed frames to `detect()`, log detections and detection latency | "Hi,ESP" at 1 m triggers in ~1/10 attempts; 30 min of ambient room audio produces no detections (record the miss rate) |
| **P3** | Event + LED flash + ack sound, codec arbitration under playback | MQTT event received by the backend; LED flashes; ack sound plays; the mic is silent and PA-off during playback; playback latency ≤ ~50 ms |
| **P4** | Persistence, `cmd/wakeup`, `status` payload, README | config survives reboot; `cmd/wakeup {"enabled":false}` stops listening without a reboot |

---

## 7. Open questions

* **OQ-1 `wn9_hiesp` channel count.** `esp_wn_iface.h` defines `DET_MODE_3CH_*` modes, and the
  ESP-SR docs list `wn9_hiesp` as a 3-channel model. If `get_channel_num()` returns 3 on a
  one-microphone board, either duplicate the mono frame into 3 interleaved channels or
  create the model with `DET_MODE_95`. P1 logs the value; §5.7 branches on it.
* **OQ-2 Frame size vs. sample rate.** `get_samp_chunksize()` is authoritative; if it is not
  512 samples / 16 kHz the capture fs in §5.7 must follow `get_samp_rate()`.
* **OQ-3 Does `esp_codec_dev_open()` on the shared `IN_OUT` handle accept a mono fs while
  playback uses stereo?** P0 verifies by opening 16 kHz/1 ch for capture and
  16 kHz/2 ch for playback on the same handle, and playing the boot sound in between.
* **OQ-4 PSRAM capacity.** Confirm from the vendor spec that 8 MB is present; the model
  needs ~350 KB in PSRAM and `DET_MODE_*_90` (flash-resident) is not an option on this board.
* **OQ-5 Power budget.** An always-on codec + mic will dominate battery life. Measure
  current with the mic open and decide whether a duty-cycle or VAD gate is required (§8).

---

## 8. Deferred work

* **Full AFE** (`esp_afe_feed` with AEC/VAD/NS) if false alarms become a problem, or if
  wake-while-playing is ever wanted. Cost: more RAM/PSRAM and a threshold API on the AFE
  instead of the model.
* **Barge-in / AEC:** not possible without the full AFE.
* **Duty cycling:** `wake.threshold` and an optional VAD gate would allow shutting the
  record path between phrases.
* **Power management:** audio rail switch-off (`Audio_PWR_PIN = GPIO42`,
  `components/user_app/user_app.cpp:26`) between duty cycles.
* **Custom "Hi Link" model:** see §10.
* **Multiple models at once:** the standalone interface handles one model per instance;
  `esp_srmodel_filter()` plus a second `create()` would be needed to listen for two words.
  Out of scope until a second bundled word is actually wanted.

---

## 9. References

* ESP-SR Wake Word Engine docs —
  <https://docs.espressif.com/projects/esp-sr/en/latest/esp32s3/wake_word_engine/README.html>
* `esp_wn_iface.h` (det modes, threshold setter, channel/chunk queries) —
  <https://github.com/espressif/esp-sr/blob/master/include/esp32s3/esp_wn_iface.h>
* `esp-sr/CMakeLists.txt` (model partition / `srmodels.bin` logic) —
  <https://github.com/espressif/esp-sr/blob/master/CMakeLists.txt>
* Model storage from SD card —
  <https://docs.espressif.com/projects/esp-sr/en/latest/esp32s3/flash_model/README.html>

---

## 10. Custom wake word ("Hi Link") — not in this phase

Renaming the `_MODEL_INFO_` display string does **not** retrain the network: the model
still recognises "Hi,ESP". A genuinely custom word needs either

* the free community route (community voice requests, tracked in
  <https://github.com/espressif/esp-sr/issues/88>), or
* Espressif's paid customization service
  (<https://docs.espressif.com/projects/esp-sr/en/latest/esp32s3/wake_word_engine/ESP_Wake_Words_Customization.html>).

Either way the model would drop into the same `/sdcard/srmodel/<name>/` layout and
`wake.model` would select it at runtime — no code change beyond the export script.

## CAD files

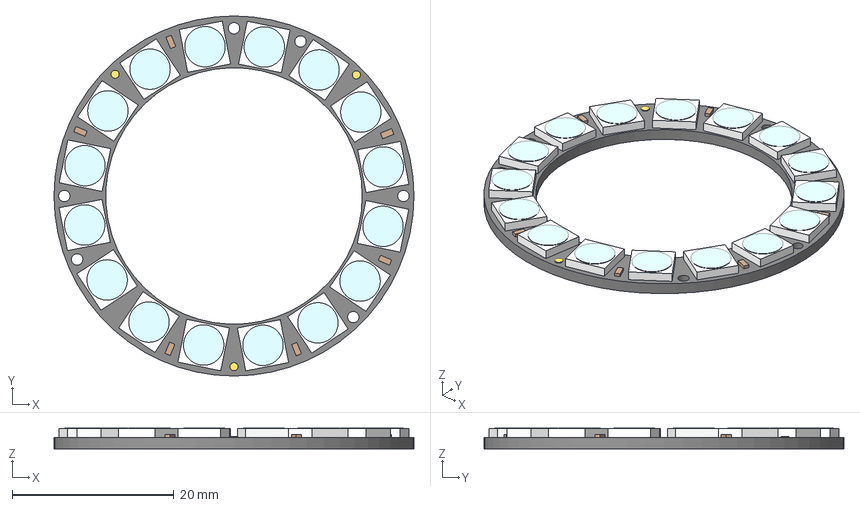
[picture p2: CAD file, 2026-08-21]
Hardware/Adafruit_NeoPixelRing16.step
44.5 x 44.5 x 2.55 mm

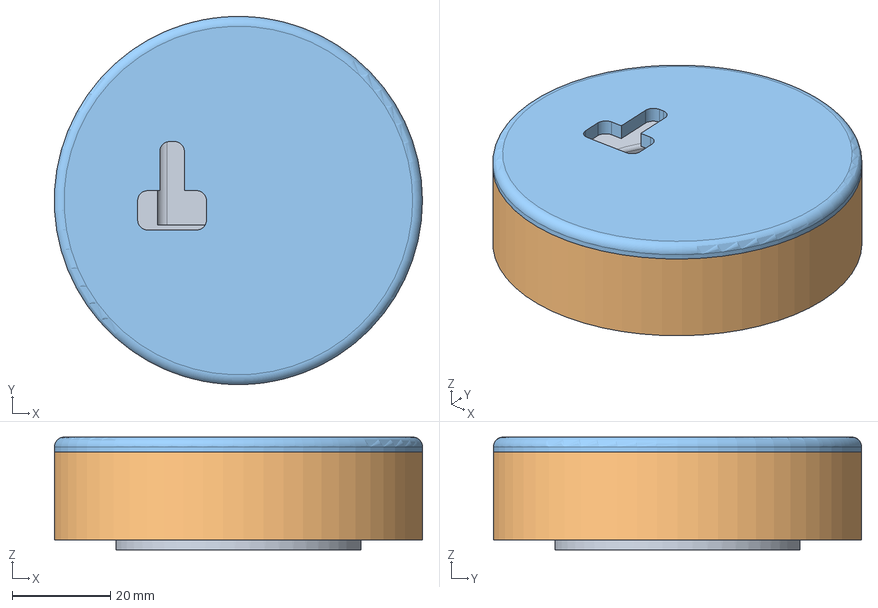
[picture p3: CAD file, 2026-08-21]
Hardware/theLink_v2.FCStd
74.9 x 75.0 x 23.0 mm
Top

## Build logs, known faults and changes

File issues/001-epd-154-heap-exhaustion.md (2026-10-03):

# 001 - Heap/DMA exhaustion on 1.54" Waveshare E-Paper after re-provisioning

| Field | Value |
|---|---|
| Status | **Partially resolved** - see [`003-epd-spi-dma-no-mem.md`](./003-epd-spi-dma-no-mem.md), [`004-security2-srp-double-free-reboot.md`](./004-security2-srp-double-free-reboot.md) and [`005-mqtt-task-start-heap.md`](./005-mqtt-task-start-heap.md) |
| Reported | 2026-10-02 |
| Branch | `fixstuff` |
| Baseline commit | `5e73940` ("untested" - adds heap instrumentation) |
| Fix commit | `8775c07` ("fix heap corruption") |
| Known-good | `5fdabd4` ("Time keeping using NTP", on `origin/master`) |
| Firmware version | `0.4.0` (`version.txt`) |

## Symptom

Pressing the re-provision button put the ESP32 into a crash loop. The logged
cause was a DMA/heap allocation failure raised while loading `dog.bin` from the
SD card.

Two details made this confusing to diagnose:

- The device booted fine on `5fdabd4` and loaded binary images without issue.
- The fault only appeared **after** the provisioning state had been reset once
  via the button. After that point, reflashing the ESP32 did **not** clear it.

## Environment

- Target: `esp32s3`, 8 MB flash, octal PSRAM @ 80 MHz (`CONFIG_SPIRAM_MODE_OCT=y`)
- ESP-IDF: v5.4.1
- Partition table: `partitions_dev.csv` (dev profile, no OTA)
- Display: Waveshare 1.54" 200x200, SPI2 host, `SPI_DMA_CH_AUTO`
- Provisioning: Wi-Fi + BLE, SoftAP/BLE transport, security version 1
- SD card: FAT, 1-bit SDMMC, `CONFIG_FATFS_LFN_HEAP=y`

## Reproduction

1. Flash `5e73940` onto a device that is already provisioned and has a valid
   `config.json` on the SD card pointing at an image (`dog.bin`).
2. Hold the reset/provision button (GPIO3, active-low) at power-up.
3. `check_reset_button_at_boot()` (`main/app_main.cpp:41`) fires and the
   firmware erases the NVS partition.
4. The device reboots into provisioning, and the crash loop follows.

## Investigation

Commit `5e73940` was the attempt to identify the reason. It added heap
instrumentation rather than a fix:

- `epaper_driver_bsp::EPD_LogHeap()` (`components/epaper_driver_bsp/epaper_driver_bsp.cpp:14`)
  dumps total free/min free internal heap, largest internal block, DMA-capable
  free, and PSRAM free.
- Call sites were added along the boot path in `main/app_main.cpp`
  (`:84`, `:119`, `:124`, `:176`, `:181`) and once in
  `components/user_app/user_app.cpp:50`.
- `main/provisioning.cpp` gained logging in the QR display callback
  (buffer pointer, scale, offset, `ui_lock()` result).
- The E-Paper SPI helpers stopped using `assert(ret == ESP_OK)` and now log the
  failure plus a heap snapshot instead (`epaper_driver_bsp.cpp:164`, `:195`, `:213`).

The instrumentation is still in the tree and is what the diagnosis below is
based on. The two `EPD_LogHeap()` calls that sat on the LVGL flush path
(`main/ui_port.cpp`) were removed once the diagnosis was complete - see
[fix 5](#5-flush-path-heap-logging-removed).

## Root cause

Heap exhaustion at the point where the boot-time allocations, the image decode,
and the Wi-Fi/BLE provisioning stack all peak together. The contributors:

1. **Concurrent large allocations.** The boot path holds, or briefly holds,
   several large buffers at once: the LVGL draw buffer `BUFF_SIZE`
   (200x200x2 = 80,000 bytes, `main/ui_port.cpp:33`), the decoded image canvas
   (80,000 bytes, `main/display_ctrl.cpp:46`), and the per-image decode
   scratchpad (40,000 bytes, `main/display_ctrl.cpp:94`). SPI/E-Paper also
   needs DMA-capable contiguous memory for `spi_device_polling_transmit()`,
   and the SPI bus is configured with `max_transfer_sz = Width * Height`
   (`epaper_driver_bsp.cpp:133`) on `SPI_DMA_CH_AUTO`
   (`epaper_driver_bsp.cpp:141`).
2. **Initialization ordering.** `provisioning_start()` ran *before* the
   display/LVGL tasks were started, and `display_ctrl::boot_kick_if_active()`
   ran *last*, after provisioning had already been kicked off. So a saved image
   referenced by `config.json` was decoded only once the Wi-Fi/BLE stack had
   already claimed its peak allocation.
3. **Allocation inside the driver constructor.** `epaper_driver_display`'s
   constructor called `heap_caps_malloc()` itself
   (`epaper_driver_bsp.cpp:80`), so the buffer's ownership and lifetime were
   implicit and allocated during boot heap churn.
4. **BLE/Wi-Fi footprint.** GATTC (GATT client) was enabled even though this
   firmware only ever acts as a GATT server during provisioning, and Wi-Fi TX
   buffers were at the default 32.
5. **Fragmentation from runtime `malloc` at peak usage.** Repeated
   allocate/free of the 40 KB decode scratchpad during the window where the
   network stack is growing fragments the internal heap and reduces the largest
   contiguous block available to DMA.

## Fixes applied

### 1. `sdkconfig.defaults` - memory footprint

| Setting | Before | After |
|---|---|---|
| `CONFIG_BT_GATTC_ENABLE` | `y` | `n` |
| `CONFIG_BT_BLE_DYNAMIC_ENV_MEMORY` | unset | `y` |
| `CONFIG_ESP_WIFI_DYNAMIC_TX_BUFFER_NUM` | 32 | 16 |
| `CONFIG_FREERTOS_USE_TRACE_FACILITY` | unset | `y` |
| `CONFIG_FREERTOS_VTASKLIST_INCLUDE_COREID` | unset | `y` |

GATTC is unused by this codebase (no `gattc` symbol appears anywhere under
`main/` or `components/`), so disabling it is free. The FreeRTOS trace options
are diagnostics for future heap/stack work.

> **Correction note.** `CONFIG_LWIP_TCP_RECVMBOX_SIZE=6`,
> `CONFIG_ESP_WIFI_RX_BA_WIN=6` and `CONFIG_ESP_WIFI_RX_MGMT_BUF_NUM_DEF=5` are
> also present in the file, but those values already matched the ESP-IDF 5.4.1
> defaults. They are **no-ops** and contributed nothing to this fix. The only
> Wi-Fi line that is a real delta is `CONFIG_ESP_WIFI_DYNAMIC_TX_BUFFER_NUM`
> (32 -> 16). The no-op lines can be pruned or annotated at convenience.

### 2. `main/app_main.cpp` - initialization order

Moved the display stack ahead of provisioning so that any image referenced by
`config.json` is decoded before the Wi-Fi/BLE stack reaches peak usage:

- `xTaskCreatePinnedToCore(example_lvgl_port_task, "LVGL", ...)`
- `led_ctrl::start()`
- `display_ctrl::start()`
- `xTaskCreate(ui_overlay_task, "ui_overlay", ...)`
- `display_ctrl::boot_kick_if_active()`

all now execute **before** `provisioning_start()`. Previously the boot kick was
the very last statement in `app_main`.

The constraint that `user_ui_init()` must precede the provisioning task is
preserved - it still runs under `ui_lock()` earlier in `app_main`, since it
calls `lv_obj_clean()` and would otherwise delete the QR widget.

### 3. E-Paper buffer ownership - `epaper_driver_bsp` + `user_app`

Added a constructor overload that accepts a caller-owned buffer:

```cpp
epaper_driver_display(int width, int height, custom_lcd_spi_t _lcd_spi_data,
                       uint8_t *external_buffer);
```

`user_app_init()` now allocates once and passes the pointer in
(`components/user_app/user_app.cpp:40`), instead of the driver allocating
internally.

> **Correction note.** This is *not* static allocation, and `MALLOC_CAP_SPIRAM`
> is the wrong capability for this buffer. It is still a `heap_caps_malloc()`,
> just hoisted to a single explicit site in `user_app_init()` so ownership and
> lifetime are visible. The original 3-argument constructor is retained and
> still allocates internally.
>
> Keeping it in PSRAM was also the direct cause of a later failure: the SPI
> master cannot DMA from PSRAM on the S3, so every panel write allocated a
> 5,000-byte internal bounce buffer, which eventually failed with
> `ESP_ERR_NO_MEM`. Corrected to `MALLOC_CAP_DMA` in
> [`003`](./003-epd-spi-dma-no-mem.md).

### 4. `main/display_ctrl.cpp` - error-path cleanup

On the decode-scratchpad allocation failure path, the `FILE *` is now closed
inside the failure branch (`main/display_ctrl.cpp:151`), and the log names the
size and region ("40KB in SPIRAM") so an OOM is distinguishable from other
failures at a glance.

### 5. Flush-path heap logging removed

`example_lvgl_flush_cb()` (`main/ui_port.cpp:93`) called `EPD_LogHeap()` on
**every** flush - once in the full-refresh branch before `EPD_Init()`, once in
the partial-refresh branch before `EPD_Init_Partial()`. Each call performed
four `heap_caps_get_free_size()`/`get_largest_free_block()` queries plus an
`ESP_LOGI`, on a path that runs for every LVGL redraw.

That instrumentation was added to diagnose this issue and is no longer needed,
so both calls were deleted. The refresh/partial-refresh logic itself is
unchanged.

`EPD_LogHeap()` itself is retained, still declared in
`components/epaper_driver_bsp/epaper_driver_bsp.h:70` and still used at:

- `components/user_app/user_app.cpp:50` - one-shot at boot, before E-Paper init.
- `components/epaper_driver_bsp/epaper_driver_bsp.cpp:165`, `:196`, `:214` -
  only on SPI transfer failure, where a heap snapshot is worth the cost.

## Verification

- `build-dev/theLink_esp32s3.bin` builds clean, no new warnings introduced by
  these changes.
- On-device: the device boots and loads the binary images.

> **Superseded in part.** Later hardware evidence (`run_1.log`, 2026-10-03) showed
> the heap pressure was reduced but not eliminated: the E-Paper SPI write still
> failed with `ESP_ERR_NO_MEM` during provisioning, leaving the QR code off the
> panel. Root cause and fix are in
> [`003-epd-spi-dma-no-mem.md`](./003-epd-spi-dma-no-mem.md). Fix 3 below was
> insufficient - see its correction note.

### Rebase onto `master` (`5fdabd4`)

The branch was rebased onto `master` after the fix was confirmed working. Both
commits replayed with conflicts confined to `sdkconfig.defaults` and
`main/app_main.cpp`. Resolutions:

- `sdkconfig.defaults` - both sides had appended to the end of the file.
  Kept **both** the `SNTP` block from `master` and this branch's memory
  optimisation block. `5e73940` also deliberately dropped the
  `CONFIG_FREERTOS_WATCHPOINT_END_OF_STACK` / `CONFIG_HEAP_POISONING_COMPREHENSIVE`
  diagnostics, whose own comment said "remove after root-causing the crash";
  that removal was honoured, so those two lines are absent.
- `main/app_main.cpp` - kept `master`'s `time_ctrl::start()`, and dropped the
  trailing "FIXED POSITION BOOT KICK" block, since `8775c07` had already moved
  `display_ctrl::boot_kick_if_active()` ahead of `provisioning_start()`.
  Keeping both would have kicked the display task twice.

Post-rebase build: 3,960,528 bytes, 52% of the app partition free. Binaries
built before the rebase are not directly comparable - `master` adds the NTP/RTC
feature set - so the size change is expected.

## Residual risk

Not addressed by this fix; tracked here so they are not lost.

1. **`assert()` on OOM paths.** `main/display_ctrl.cpp:47` and
   `components/user_app/user_app.cpp:41` still abort the device on allocation
   failure rather than degrading (blank canvas / skip update). The
   decode-scratchpad path (`display_ctrl.cpp:94`) already handles `NULL`
   gracefully; the other two do not.
2. **Only one image is decoded at a time by luck, not by design.** The
   `s_state.active` flag plus the notify-count in `display_ctrl` mean a second
   notification arriving during a decode is dropped rather than queued. Fine
   today, fragile if the download path starts issuing overlapping updates.
3. **`main/app_main.cpp` has no trailing newline** (pre-existing, carried over
   from the reorder).
4. **No regression test.** The crash depends on SD-card contents, NVS state,
   and boot timing. There is no automated way to reproduce it, so a regression
   would not be caught by CI.

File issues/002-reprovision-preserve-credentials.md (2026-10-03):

# 002 - Re-provisioning should not obliterate existing Wi-Fi credentials

| Field | Value |
|---|---|
| Status | **Open** - design discussion only, not implemented |
| Raised | 2026-10-02 |
| Branch | `fixstuff` (design captured alongside the 001 fix) |
| Related | [`001-epd-154-heap-exhaustion.md`](./001-epd-154-heap-exhaustion.md), [`003-epd-spi-dma-no-mem.md`](./003-epd-spi-dma-no-mem.md) |

## Problem

Holding the provisioning button at boot is a hard factory reset: it erases the
entire NVS default partition, destroying stored Wi-Fi credentials. Two paths
cause this:

1. `check_reset_button_at_boot()` (`main/app_main.cpp:41`, GPIO3, active-low)
   sets `dynamic_factory_reset` (`main/app_main.cpp:86`), and the handler calls
   `nvs_flash_erase()` at `main/app_main.cpp:94` with the comment
   *"This completely wipes the default NVS partition where credentials live."*
2. `main/provisioning.cpp:529` also calls
   `network_prov_mgr_reset_wifi_provisioning()` under
   `CONFIG_EXAMPLE_RESET_PROVISIONED`, which is `esp_wifi_restore()` internally.

## Why re-provisioning never re-triggers

The binding constraint is the provisioned-state gate. `provisioning.cpp:536`
gates the provisioning service behind `if (!provisioned)`, where
`provisioned` comes from `network_prov_mgr_is_wifi_provisioned()`
(`provisioning.cpp:532`). That function reads the live STA config and returns
true whenever an SSID is set - it is not a separate provisioning-state flag.

So with credentials present, `provisioned == true`, the service never starts,
and the only way to re-enter provisioning is to destroy those credentials
first. The two behaviours are circularly coupled. Any fix must break that
coupling.

## Design options

### Option A - Custom reprovision flag

Remove `nvs_flash_erase()` from `main/app_main.cpp:94`. On button press, write
a `reprovision_requested` flag into a *non-erased* NVS namespace. Gate
provisioning on `provisioned || reprovision_requested`, allowing new
credentials to overwrite old ones in the default namespace while keeping the
old credentials available for fallback.

Trade-off: we own the state machine, including deciding when to clear the flag.

### Option B - `network_prov_mgr_reset_wifi_sm_state_for_reprovision()`

The upstream manager already provides a non-destructive reset
(`network_prov_mgr_reset_wifi_sm_state_for_reprovision()`,
`managed_components/espressif__network_provisioning/src/manager.c:2385`).
It explicitly keeps storage in RAM (`esp_wifi_set_storage(WIFI_STORAGE_RAM)`
at `:2404`), clears only the in-RAM STA config, disconnects, restores
`WIFI_STORAGE_FLASH`, resets `prov_ctx->prov_state`, and fires
`NETWORK_PROV_START`. NVS credentials are never touched.

Two real constraints:

- It calls `execute_event_cb(NETWORK_PROV_START, ...)`, which conflicts with the
  existing `NETWORK_PROV_END` handling that tears the manager down
  (`main/provisioning.cpp:362`). Wiring this into the current event flow needs
  care around manager lifetime.
- It does not remove the `provisioned` gate; the button state must still be
  tracked separately to get past `provisioning.cpp:536`.

### Option C - Runtime button instead of boot-only

Detect a long press on the factory-reset button after boot, so the button
changes provisioning state directly instead of depending on the
`check_reset_button_at_boot()` flag. Removes the timing sensitivity, but is a
larger change to the input path.

## Credential storage caveat

Worth resolving before any of the options is written: the ESP-IDF Wi-Fi driver
keeps a single STA config slot in NVS. `esp_wifi_set_config(...,
WIFI_STORAGE_FLASH)` overwrites that slot on every call, and the provisioning
manager writes the freshly received credentials into it immediately.

Consequence: once new credentials land, the old ones are gone - there is no
second slot to fall back to. A genuine "keep the old credentials if no new
ones arrive" guarantee therefore likely needs an explicit shadow copy in our
own NVS namespace, saved before provisioning starts and restored on timeout or
explicit abort. Whether that is acceptable needs a decision before coding.

## Related hazard

`main/provisioning.cpp:351` calls
`network_prov_mgr_reset_wifi_sm_state_on_failure()` when
`CONFIG_EXAMPLE_RESET_PROV_MGR_ON_FAILURE` is set (default `y`,
`main/Kconfig.projbuild:109`, `EXAMPLE_PROV_MGR_CONNECTION_CNT` default 5).
That path also drops credentials after retries, so a user with working Wi-Fi
who mistypes a password during re-provisioning ends up with no credentials at
all - the same data-loss class as this issue, reached by a different route.

## Open questions

- Should re-provisioning attempt the new SSID, then fall back to the stored one
  on failure, or leave the existing connection untouched until the new one is
  proven?
- Is a provisioning timeout needed, and how long?
- Should the shadow copy of old credentials survive across the reboot, or only
  for the session?
- Does the user expect the button to be usable after boot (runtime long-press),
  or only at power-up as today?

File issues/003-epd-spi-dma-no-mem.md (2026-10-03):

# 003 - QR code not displayed in provisioning mode (E-Paper SPI write fails)

| Field | Value |
|---|---|
| Status | **Fixed** - confirmed on device (QR displays and scans) |
| Found | 2026-10-03 |
| Evidence | `/home/savio/run_1.log` |
| Device log version | `0.4.1`, ESP-IDF v5.4.1, esp32s3 |
| Branch | `fixstuff` |
| Related | [`001-epd-154-heap-exhaustion.md`](./001-epd-154-heap-exhaustion.md) |

## Symptom

In provisioning mode the screen never shows the QR code. The provisioning
service itself starts correctly and the QR payload is generated and pushed to
LVGL, but the panel is never updated.

From `run_1.log`:

```
I (2270) app: Provisioning started
I (2280) QRCODE: Encoding below text with ECC LVL 0 & QR Code Version 10
I (2390) QR_UI: qr_pixel_buffer=0x3c3e1e24, scale=5, offset=(7,7)
I (4200) QR_UI: ui_lock returned 1
I (4200) QR_UI: Successfully pushed binary QR image payload onto layout engine matrix.
I (4470) FLUSH: Executing Global Full Refresh -> Black: 17900, White: 22100
E (4470) driver: writeBytes(5000 bytes) failed: ESP_ERR_NO_MEM
I (4470) driver: [HEAP] writeBytes failure: total_free=8120116, total_min=8113516
                | INTERNAL free=18003, largest_blk=7168 | DMA free=10499 | SPIRAM free=8102328
```

## Root cause

`EPD_Display()` calls `writeBytes(buffer, 5000)` to push the packed 1-bit frame
to the controller. That transfer fails with `ESP_ERR_NO_MEM`, so **no pixels
reach the glass**. Two defects combined to make it invisible.

### 1. The panel buffer was allocated in PSRAM, forcing a per-transfer allocation

`epd_static_buffer` was allocated with `MALLOC_CAP_SPIRAM`. On the ESP32-S3,
`esp_ptr_dma_capable()` is a range check against **internal** SRAM only:

```c
// components/esp_hw_support/include/esp_memory_utils.h:212
inline static bool esp_ptr_dma_capable(const void *p)
{ return (intptr_t)p >= SOC_DMA_LOW && (intptr_t)p < SOC_DMA_HIGH; }

// components/soc/esp32s3/include/soc/soc.h:205
#define SOC_DMA_LOW  0x3FC88000
#define SOC_DMA_HIGH 0x3FD00000
```

That window does not contain PSRAM. The SPI master therefore treats a PSRAM
source as non-DMA-capable and allocates a fresh internal bounce buffer on
**every** transfer:

```c
// components/esp_driver_spi/src/gpspi/spi_master.c:1152
if ((!esp_ptr_dma_capable(send_ptr) || tx_unaligned)) {
    tx_byte_len = (tx_byte_len + alignment - 1) & (~(alignment - 1));
    uint32_t *temp = heap_caps_aligned_alloc(alignment, tx_byte_len, MALLOC_CAP_DMA);
    if (temp == NULL) {
        goto clean_up;      // -> ESP_ERR_NO_MEM
    }
    memcpy(temp, send_ptr, (trans_desc->length + 7) / 8);
    send_ptr = temp;
}
```

`SOC_PSRAM_DMA_CAPABLE` *is* 1 on the S3, but this code path does not use the
external-DMA-aware helper (`esp_dma_is_buffer_aligned(..., AUTO)` /
`esp_ptr_dma_ext_capable()`), so it never benefits from it. In IDF 5.4.1 a
PSRAM SPI source always bounces.

The 5,000-byte bounce allocation is what fails. Note the heap figures: the
`largest_blk=7168` reading is for `MALLOC_CAP_INTERNAL|MALLOC_CAP_8BIT`, which
is a *different pool* from `MALLOC_CAP_DMA` (`free=10499`). The DMA pool is
fragmented well below a contiguous 5,000 bytes by this point in boot.

### 2. The failure was silent

`writeBytes()` only logged and returned. `example_lvgl_flush_cb()`
(`main/ui_port.cpp:156`) then called `lv_disp_flush_ready()` unconditionally, so
LVGL believed the flush succeeded. No retry, no error propagation, and the
panel was left showing the previous frame. This is why the failure presented as
"QR not displayed" with no visible error path.

### Why this window is so tight

The heap collapses between `provisioning_start()` and the QR flush. From the log:

| Point in boot | INTERNAL free | largest block |
|---|---|---|
| after `user_app_init` | 205,287 | 110,592 |
| after `display_ctrl::start` | 137,323 | 43,008 |
| after `provisioning_start` | 131,491 | 36,864 |
| at the failed QR flush | **18,003** | **7,168** |

Roughly 113 KB of internal RAM is consumed in that window by BLE, the I2S/codec
buffers, the PCF85063 RTC and Wi-Fi. Wi-Fi alone is configured for
`dynamic rx buffer num: 32` at ~1,600 bytes each, on the order of 51 KB of
internal DMA memory.

The reordering from issue 001 (display before provisioning) helps the *first*
refresh at 2420 ms, which succeeds with room to spare. The QR refresh lands
2 seconds later, in the worst window.

## Fix

### Panel buffer must be DMA-capable internal RAM

```c
// components/user_app/user_app.cpp
- epd_static_buffer = (uint8_t *)heap_caps_malloc(5000, MALLOC_CAP_SPIRAM);
+ epd_static_buffer = (uint8_t *)heap_caps_malloc(5000, MALLOC_CAP_DMA);
```

With the buffer inside `SOC_DMA_LOW..SOC_DMA_HIGH`, `esp_ptr_dma_capable()`
returns true. The alignment condition is also satisfied -
`internal_mem_align_size` is 4 (`spi_common.c:846`), `heap_caps_malloc` returns
4-byte-aligned pointers and `5000 % 4 == 0` - so `tx_unaligned` is false and
**no bounce buffer is allocated at all**. The transfer becomes allocation-free
for the lifetime of the driver.

This is allocated once at `user_app_init()`, when internal free is still
205,287 bytes, so the 5,000 bytes are obtained from a healthy heap rather than
competing at flush time.

Note this partially reverses fix 3 of issue 001. That fix correctly moved the
allocation out of the driver constructor and made ownership explicit, but it
kept `MALLOC_CAP_SPIRAM`, which is the wrong capability for an SPI DMA source.
The external-buffer constructor overload is what made the capability flag
correctable in one place.

### Transfer failures are no longer silent

Added a private helper that retries once and reports honestly:

```c
// components/epaper_driver_bsp/epaper_driver_bsp.cpp
esp_err_t epaper_driver_display::spi_transmit_with_retry(spi_transaction_t *t, const char *what) {
    esp_err_t ret = spi_device_polling_transmit(spi, t);
    if (ret == ESP_OK) return ret;
    ESP_LOGW(TAG, "%s failed: %s - retrying once", what, esp_err_to_name(ret));
    vTaskDelay(pdMS_TO_TICKS(50));
    ret = spi_device_polling_transmit(spi, t);
    if (ret != ESP_OK) {
        ESP_LOGE(TAG, "%s failed again after retry: %s - panel will show a stale frame", ...);
        EPD_LogHeap(what);
    }
    return ret;
}
```

`SPI_SendByte()` and both `writeBytes()` overloads now route through it, and the
log message names the transfer and states that the frame is stale, so a future
failure is diagnosable instead of looking like a successful flush.

## Verification

- Builds clean; `theLink_esp32s3.bin` at 3,960,528 bytes, 52% of the app
  partition free.
- The bounce-allocation path is provably not taken (source-level: the buffer is
  inside the DMA window and 4-byte aligned).
- **On-device confirmed.** The user flashed the fixed firmware and reported
  that the QR code renders and the provisioning app scans it. The
  `writeBytes(...) failed: ESP_ERR_NO_MEM` line is gone.

## Follow-ups not done here

1. **Internal heap headroom is still thin.** 18,003 bytes free at the QR flush
   is enough now that the SPI path allocates nothing, but very little slack for
   anything else. Consider
   `CONFIG_ESP_WIFI_DYNAMIC_RX_BUFFER_NUM=16` (from 32) in `sdkconfig.defaults`,
   worth roughly 25 KB of internal DMA. Left unchanged here because it trades
   Wi-Fi RX throughput and should be an explicit decision.
   **Done** in [`005-mqtt-task-start-heap.md`](./005-mqtt-task-start-heap.md),
   where the thin internal heap turned out to be what stopped `mqtt_task` from
   being created after provisioning.
2. **`lv_disp_flush_ready()` is still called unconditionally** at
   `main/ui_port.cpp:156`, regardless of whether the panel write succeeded. The
   retry helper now makes the failure loud, but the flush callback still does
   not propagate it. Worth wiring up so LVGL state and panel state cannot
   diverge silently.
3. **The QR refresh is a full-screen refresh.** The 200x200 full blink cycle
   takes 100-500 ms. A partial refresh would be faster and would leave more
   headroom, but only if the QR widget bounds are used to size the update area.

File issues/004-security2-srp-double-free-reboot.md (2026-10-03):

# 004 - Device reboots when a BLE provisioning client connects (security2 SRP double free)

| Field | Value |
|---|---|
| Status | **Fixed** - awaiting on-device confirmation |
| Found | 2026-10-03 |
| Evidence | `/home/savio/run_2.txt` |
| Device log version | `0.4.1`, ESP-IDF v5.4.1, esp32s3 |
| Branch | `fixstuff` |
| Related | [`001-epd-154-heap-exhaustion.md`](./001-epd-154-heap-exhaustion.md), [`003-epd-spi-dma-no-mem.md`](./003-epd-spi-dma-no-mem.md) |

## Symptom

Provisioning starts, the QR code renders and scans, and the client connects.
The moment the security2 handshake runs, the device asserts and reboots. It
repeats on every attempt.

From `run_2.txt`:

```
I (33377) BLE transport: Connected!
I (35017) security2: Using salt and verifier to generate public key...
mbedtls_mpi_mod_mpi() failed, returned fffffff0
E (35267) security2: Failed to generate device session key!
E (35277) security2: Session setup error -1
E (35277) protocomm_ble: Invalid content received, killing connection
W (35287) BT_HCI: hci cmd send: disconnect: hdl 0x1, rsn:0x13

assert failed: heap_caps_free heap_caps_base.c:74 (heap != NULL && "free() target pointer is outside heap areas")
...
rst:0xc (RTC_SW_CPU_RST), boot:0x8 (0x40018000)
```

## Root cause

Two separate defects stack up. The first only aborts the handshake; the second
turns that abort into a reboot.

### 1. Trigger: mbedTLS could not allocate, because it was locked out of PSRAM

`mbedtls_mpi_mod_mpi() failed, returned fffffff0` is not a crypto error.
`0xfffffff0` is `-0x0010`, which is `MBEDTLS_ERR_MPI_ALLOC_FAILED` in
`mbedtls/bignum.h`. The bignum code simply ran out of heap.

The cause is a memory-cap restriction. `CONFIG_MBEDTLS_INTERNAL_MEM_ALLOC=y`
made every mbedTLS allocation use:

```c
heap_caps_calloc(n, size, MALLOC_CAP_INTERNAL|MALLOC_CAP_8BIT);
```

(`components/mbedtls/port/esp_mem.c`). `MALLOC_CAP_INTERNAL` excludes PSRAM, so
none of the 8 MB of PSRAM was available to mbedTLS. Meanwhile the internal heap
is what the BLE and Wi-Fi stacks, LVGL and the E-Paper driver all contend for.
By the time the phone connects, the log shows the internal heap down to
`largest_blk=32768`:

```
I (2027) app: [HEAP] after display_ctrl::start: INTERNAL free=132199, largest_blk=38912
I (2047) app: [HEAP] after provisioning_start: INTERNAL free=126367, largest_blk=32768
```

So the SRP6a temporaries for a 3072-bit group could not be allocated, and
session setup returned `ESP_FAIL`.

### 2. The crash: `protocomm` double-frees the SRP handle on every setup failure

This is the actual reboot, and it is an upstream ESP-IDF defect in
`components/protocomm/src/security/security2.c`. Five error paths free the
session's SRP handle and return without clearing the pointer:

```c
if (esp_srp_get_session_key(cur_session->srp_hd, ..., &cur_session->session_key,
                            &cur_session->session_key_len) != ESP_OK) {
    ESP_LOGE(TAG, "Failed to generate device session key!");
    esp_srp_free(cur_session->srp_hd);   // freed...
    return ESP_FAIL;                      // ...but srp_hd is left dangling
}
```

The same pattern repeats at the salt/verifier, device-pubkey, response-allocation
and username-allocation failure paths. Because `cur_session->srp_hd` is still
non-NULL and now dangling, the subsequent BLE disconnect frees it **again**:

```
sec2_close_session (security2.c:400)  ->  if (cur_session->srp_hd) esp_srp_free(...)
```

The second `esp_srp_free()` reads `hd->ctx` out of memory that has already been
freed and handed back to the Bluetooth stack, so the pointer is garbage. It is
passed to `mbedtls_mpi_free()`, which tries to release the limb buffer at that
address and trips the allocator's own consistency check:

```
assert failed: heap_caps_free heap_caps_base.c:74 (heap != NULL && "free() target pointer is outside heap areas")
```

### Backtrace

Decoded against the exact crashing image (ELF SHA-256 prefix `e93687162`,
preserved at `/tmp/opencode/theLink_crash_e93687162.elf`):

```
heap_caps_free            heap/heap_caps_base.c:74      <- assert
esp_mbedtls_mem_free      mbedtls/port/esp_mem.c:38
mbedtls_free              mbedtls/library/platform.c:54
mbedtls_zeroize_and_free  mbedtls/library/platform_util.c:145
mbedtls_mpi_free          mbedtls/library/bignum.c:198
esp_mpi_free              protocomm/src/crypto/srp6a/esp_srp_mpi.c:54
esp_mpi_ctx_free          protocomm/src/crypto/srp6a/esp_srp_mpi.c:67
esp_srp_free              protocomm/src/crypto/srp6a/esp_srp.c:141
sec2_close_session        protocomm/src/security/security2.c:400
transport_simple_ble_disconnect  protocomm/src/transports/protocomm_ble.c:347
gatts_profile_event_handler      protocomm/src/simple_ble/simple_ble.c:168
btc_thread_handler / vPortTaskWrapper
```

## Fix

Switch mbedTLS to allocate from PSRAM instead of the internal heap:

```
CONFIG_MBEDTLS_EXTERNAL_MEM_ALLOC=y
```

added to `sdkconfig.defaults`, so both the Dev and Prod profiles pick it up.
`esp_mbedtls_mem_calloc()` then uses `MALLOC_CAP_SPIRAM|MALLOC_CAP_8BIT` and
the SRP6a temporaries come from the 8 MB of PSRAM that was sitting idle. The
IDF `Kconfig` help recommends exactly this mode for devices where internal
memory is tight, and notes that on the ESP32-S3 it is also safe from a security
 standpoint when flash encryption is used.

This removes the allocation failure, so session setup now succeeds and the
double-free path in defect 2 is never entered.

## Follow-ups not done here

1. **The double-free is still latent.** This fix stops the trigger, not the
   bug. Any other reason for security2 setup to fail - a malformed client
   request, an unexpected username - walks the same
   `esp_srp_free()` / `esp_srp_free()` path and reboots the device the same
   way. The real repair is to null `cur_session->srp_hd` after freeing it on
   all five paths. That lives in `protocomm`, an IDF component outside this
   repository, so fixing it means carrying a local patch or vendored override.
   Worth tracking before this reaches production.
2. **`esp_mpi_a_mul_b_mod_c()` leaks on its error path**
   (`protocomm/src/crypto/srp6a/esp_srp_mpi.c:105`). It builds `t` with
   `mbedtls_mpi_mul_mpi()` and returns without `mbedtls_mpi_free(&t)` when the
   following `mbedtls_mpi_mod_mpi()` fails. `esp_mpi_a_add_b_mod_c()` has the
   same shape. Harmless while setup succeeds, but it leaks on every failure.

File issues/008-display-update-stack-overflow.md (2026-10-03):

# 008 - Stack overflow in `display_update` when pushing an image to the e-paper canvas

| Field | Value |
|---|---|
| Status | **Fixed** - confirmed on device |
| Found | 2026-10-03 |
| Evidence | Crash: `/home/savio/run4.txt` - fix confirmed: `/home/savio/run_6.txt` |
| Device log version | `0.4.1`, ESP-IDF v5.4.1-dirty, esp32s3 |
| Baseline ELF | `ba80da3bbf9d9ac9719526d13e40dc979c6f192dc43605656637cf1eb9bd48f` (compile time `Oct  3 2026 12:25:53`) |
| Fixed ELF | `ab15e5c31...` (compile time `Oct  3 2026 15:18:41`) |
| Branch | `fixstuff` |
| Related | [`001-epd-154-heap-exhaustion.md`](./001-epd-154-heap-exhaustion.md), [`003-epd-spi-dma-no-mem.md`](./003-epd-spi-dma-no-mem.md), [`004-security2-srp-double-free-reboot.md`](./004-security2-srp-double-free-reboot.md), [`005-mqtt-task-start-heap.md`](./005-mqtt-task-start-heap.md) |

This issue is **independent of the security2 work**. The crashing firmware is
the pre-security2 baseline ELF, and the faulting task (`display_update`) is not
touched by anything in `components/protocomm`.

## Symptom

Pushing a second and third image into the e-paper canvas in the same boot
session aborts with a FreeRTOS stack overflow in `display_update`:

```
I (57011) app: Unpacking 41KB I8 Asset from SD Card: /sdcard/dog.bin
I (57111) app: Unpacking complete. Pushing canvas to widget container...
I (57291) FLUSH: Executing Global Full Refresh -> Black: 15066, White: 24934
I (68271) app: Display command received
I (68271) app: Display download: http://80.225.207.106/esp32_images/us.bin -> us.bin
I (68301) app: File already available at: /sdcard/us.bin
I (68301) app: Updating display state with new data path: /sdcard/us.bin
I (68321) app: Notifying display task of new data path: /sdcard/us.bin
I (68321) app: Unpacking 41KB I8 Asset from SD Card: /sdcard/us.bin
I (68381) app: Unpacking complete. Pushing canvas to widget container...

***ERROR*** A stack overflow in task display_update has been detected.

Backtrace: 0x403760a1:0x3fcde580 0x40384951:0x3fcde5a0 0x4038586e:0x3fcde5c0
           0x403875e3:0x3fcde640 0x40385934:0x3fcde660 0x4038592a:0x3fcab4a4 |<-CORRUPTED
```

The abort happens between the "Unpacking complete" log and the flush. Note that
`dog.bin` rendered normally 11 seconds earlier on the identical code path, and
that heap was byte-for-byte identical for both commands:

```
I (57011) app: [HEAP] handle_display_command: total_free=8227844 | INTERNAL free=52471, largest_blk=25600   <- dog.bin, OK
I (68271) app: [HEAP] handle_display_command: total_free=8227844 | INTERNAL free=52471, largest_blk=25600   <- us.bin, overflow
```

After the device rebooted, the *same* `/sdcard/us.bin` pushed successfully at
`t=2107` and four further images pushed cleanly. The failure is intermittent
and not tied to any particular image.

## Root cause

The task stack was too small for the work the task does, with no margin left
for interrupt frames.

### 1. A 1 KiB buffer sat on the stack

`display_update_task` declared the palette as a local inside the unpack path:

```cpp
/* main/display_ctrl.cpp:90 (before fix) */
uint8_t palette[1024];
fread(palette, 1, 1024, f);
```

Disassembling the object confirms how much of the frame that consumed:

```
$ xtensa-esp32s3-elf-objdump -d build/esp-idf/main/CMakeFiles/__idf_main.dir/display_ctrl.cpp.obj
00000000 <_ZL19display_update_taskPv>:
   0:   088136    entry   a1, 0x440        <- 1088-byte frame
```

1088 bytes of static locals against a 4096-byte stack, i.e. the palette alone
consumed a quarter of the budget before a single call was made. The remaining
~3 KB had to cover `fopen`/`fseek`/`fread` (newlib + FatFS), `std::string`
copy/assign under a `std::mutex`, the `ESP_LOGI` varargs formatting, and the
LVGL invalidate chain. The individual LVGL frames are modest
(`lv_image_set_src` 0x80, `lv_image_decoder_get_info` 0x112, `lv_refr_join_area`
0x48), so this is cumulative exhaustion rather than one pathological frame.

### 2. The 200x200 flush is not the culprit

Worth ruling out explicitly, because it is the obvious suspect: the flush does
**not** run on this stack. `ui_lock`/`ui_unlock` bracket only the LVGL object
mutation, and the actual E-Paper transfer is driven later by `lv_timer_handler`
on the separate 8192-byte LVGL task (`main/app_main.cpp:174`). The 100-500 ms
gap between "Pushing canvas" (`t=68381`) and `FLUSH:` is that hand-off. Growing
the flush path's stack would not have fixed anything.

### 3. Interrupts run on the task's stack, which is what makes it intermittent

This is the part that explains why a marginally-sized stack fails sometimes and
not otherwise. ESP-IDF services interrupts on the interrupted task's stack, so
this task's 4 KB had to absorb nested Wi-Fi, SPI and SDMMC frames while doing
file I/O. At the crash timestamp the log shows live Wi-Fi association activity
(`wifi:connected with Cardoz` at `t=4557`, state transitions right through the
window), so the interrupt load was real.

That makes the fault a race against interrupt-frame arrival rather than a
property of any image. Both the heap reading and the code path were identical
between the succeeding and failing push, which is exactly the signature of an
ISR-timing-dependent overflow. Heap exhaustion is ruled out independently:
`free=52471`, `largest_blk=25600` at the fault.

### 4. Why the backtrace was unusable

`CONFIG_FREERTOS_CHECK_STACKOVERFLOW_CANARY=y` (`build/sdkconfig:1741`) means
detection happens at a context switch, not at the fault site. The reported
frames are therefore the dispatcher/panic path, not the overflowing call chain:

- consecutive stack pointers differ by only `0x20`, consistent with the switch path;
- the final frame is `<-CORRUPTED`.

This is also why obtaining the matching `ba80da3bb` ELF would **not** have
recovered the real frames. The `main` symbols resolved against the current ELF
land in `vApplicationStackOverflowHook` / `vTaskSwitchContext` /
`_frxt_dispatch`, confirming the diagnosis. Correct action was to measure peak
usage rather than chase symbols.

## Fix

Two changes in `main/display_ctrl.cpp`, applied together.

### Move the palette into SPIRAM

```cpp
// The 1,024-byte palette is kept in SPIRAM rather than as a local: this task
// runs a tight stack and the local cost is significant. See issues/008.
static uint8_t *palette = (uint8_t *)heap_caps_malloc(1024, MALLOC_CAP_SPIRAM);
assert(palette != NULL);
```

Placed next to the existing 80 KB PSRAM canvas, and initialised once before the
notify loop alongside it. The 1024 bytes now come from PSRAM instead of the
stack, so the frame drops from 1088 bytes to roughly 64. The `static` local is
still a pointer, so the allocation happens exactly once, on first pass through
that code, and the lifetime matches the other `static` buffers. The `assert`
mirrors the adjacent canvas allocation so a failed PSRAM init fails loudly at
task start rather than corrupting memory later.

### Raise the task stack to 8192 bytes

```cpp
// main/display_ctrl.cpp:start()
xTaskCreate(display_update_task, "display_update", 8192, NULL, 4, &s_display_task_handle);
```

8192 is not an arbitrary figure. ESP-IDF's `xTaskCreate` takes **bytes** (not
words) - the repo already documents this at `main/data_downloader.cpp:238-240`,
where the same measurement convention is why the storage and HTTP tasks use
8192. This makes `display_update` consistent with the three other
image/audio-heavy tasks:

| Task | Stack | Location |
|---|---|---|
| `LVGL` | 8192 | `main/app_main.cpp:174` |
| `audio_play` | 8192 | `main/audio_ctrl.cpp:198` |
| `StorageTask` | 8192 | `main/data_downloader.cpp:240` |
| `HttpTask` | 8192 | `main/data_downloader.cpp:249` |
| **`display_update`** | **4096 -> 8192** | `main/display_ctrl.cpp:278` |

Both changes are needed. Moving the palette alone frees stack but does nothing
for ISR nesting; raising the stack alone leaves a 1 KiB buffer on a task whose
problem is marginal headroom.

### Instrument the high-water mark

```cpp
ESP_LOGI(TAG, "Display push complete: %s. Stack HWM=%" PRIu32,
         file_path.c_str(), (uint32_t)uxTaskGetStackHighWaterMark(NULL));
```

Logged after each successful push, i.e. after the deepest path has run.
`uxTaskGetStackHighWaterMark` reports the *lowest* free level ever reached, which
is precisely the quantity the canary compares against, so this number predicts
the fault rather than merely describing it. The pattern is copied from the
existing logging at `main/data_downloader.cpp:59-60` and `:190-191`.

This matters because a stack bump can otherwise convert a loud crash into a
silent one: had 4096 overflowed and the stack simply been raised to 8192, the
same defect could resurface much later with a corrupted backtrace and no
warning. With the log line present, an approaching overflow is visible in the
serial output as a shrinking HWM.

## Cost of the fix

Task stacks are allocated from **internal** RAM, not PSRAM, so the 4 KB is
permanent internal-heap pressure. Internal heap is already the tight resource
in this firmware:

- tightest observed internal free in the capture is **49,735 bytes** with
  `largest_blk=24,576` (`run4.txt:501`), at the moment an HTTP download starts;
- `CONFIG_SPIRAM_MALLOC_ALWAYSINTERNAL=16384` and
  `CONFIG_SPIRAM_MALLOC_RESERVE_INTERNAL=32768` mean allocations below 32 KB are
  forced to internal and cannot spill to PSRAM.

So 4 KB is roughly 8% of worst-case internal free. `display_update` is created
at `main/app_main.cpp:176`, before `provisioning_start`, so the charge lands
early: expect the post-`display_ctrl::start` reading to fall from
`INTERNAL free=131,887` (`run4.txt:115`) to about 127,900, with every later
internal-heap reading shifted down by the same 4 KB. This is the direct
consequence of the fix and is accepted deliberately, in exchange for removing
a crash; it is recorded here so a future heap regression can be attributed
correctly.

Measured on the fixed build, the prediction was accurate to 16 bytes:

| | `after display_ctrl::start` | stack |
|---|---|---|
| baseline (`run4.txt:115`) | `INTERNAL free=131,887` | 4096 |
| fixed (`run_6.txt:256`) | `INTERNAL free=127,823` | 8192 |
| delta | **4,064 bytes (3.97 KB)** | |

## Verification

**Confirmed** in `/home/savio/run_6.txt` on fixed ELF `ab15e5c31...` (compile
time `Oct  3 2026 15:18:41`, matching the local build). All checks passed.

| # | Check | Result |
|---|---|---|
| 1 | No `stack overflow in task display_update` across the session | **pass** - zero occurrences in 355 lines |
| 2 | `Stack HWM=` present on every push | **pass** - 9 pushes, 9 readings |
| 3 | HWM stable, not falling | **pass** - `5208` on all 8 warm pushes |
| 4 | `Unpacking complete` followed by `FLUSH:` | **pass** - 9/9, Black/White counts varied per image |
| 5 | `after display_ctrl::start` heap drop ~4 KB | **pass** - 4,064 bytes (above) |
| 6 | Images render correctly | **pass** (operator-confirmed) |

Nine images pushed in one session, including three downloaded fresh rather than
served from SD cache (`worldtravel.bin`, `cat.bin`, `rose.bin`), plus a reboot
and a further push. This is the scenario that used to fail on the second/third
push. No E- or W-level log lines appear anywhere in the capture.

### The measurement closes the diagnosis

`uxTaskGetStackHighWaterMark` reports the *minimum free* level, so peak task
usage is `8192 - 5208 = 2984` bytes. The pre-fix frame was 1088 bytes against
the current 80, so implied peak usage before the fix was roughly
`2984 + (1088 - 80) = 3992` bytes against a 4096-byte stack:

| | stack | peak usage | headroom |
|---|---|---|---|
| before | 4096 | ~3992 | **~104 bytes** |
| after | 8192 | 2984 | **5208 bytes** |

That ~104-byte margin is the whole bug. It explains three things at once:

- why `dog.bin` and `us.bin` both fit *just barely* on identical code paths,
- why the fault was intermittent, since ISR nesting only had ~104 bytes to
  work with, and
- why it took a Wi-Fi-active window to trip rather than failing every time.

It also confirms the ISR reasoning in the root-cause section was the right
explanation: the task path alone did not overflow. It ran out of room when
interrupts were added to it. Note this means the stack bump was the load-bearing
change - moving the palette alone would have bought back only ~1008 of those
104 bytes of headroom, leaving the margin at roughly 1112 bytes rather than
comfortable.

The boot-session reading differs (`HWM=6120` on the first post-reboot push,
`run_6.txt:295`) because less nesting had occurred at that point - Wi-Fi was
still associating and the flush had not run yet. Steady state is `5208`, and it
does not degrade as pushes accumulate, so there is no leak in the push path.

Unrelated but reassuring: `StorageTask`/`HttpTask` HWM (`3180`/`2928`) are also
steady, and `Storage Task: launch returned pdPASS` throughout, so the 4 KB
taken by `display_update` did not starve the download path.

## Follow-ups not done here

1. **Internal heap headroom is the next real constraint.** `largest_blk` falls
   from 106,496 to 36,864 across `display_ctrl::start` (`run4.txt:115`) - a
   single allocation larger than the entire stack increase above. That is not
   part of this fix, but it is a bigger consumer than anything discussed here
   and deserves its own look before more permanent internal allocations are
   added.
2. **A 4096-byte overflow could now be an 8192-byte overflow.** The HWM log is
   the mitigation, but nothing alerts on it. A threshold warning (or a
   `status_ctrl` publish when HWM drops below some margin) would turn a future
   regression into an event rather than a log line somebody has to notice.
3. **ISR nesting on this task is unbounded regardless of stack size.** 8192
   gives real headroom but does not bound interrupt depth. The measurement
   above shows the push path peaks at 2984 bytes, so the remaining 5208 is
   genuinely ISR/interrupt-frames allowance and is what keeps this safe. If a
   future change pushes HWM much lower, the durable fix is to move the file
   I/O off this task (or onto the other core) rather than to keep growing the
   stack. Worth knowing which factor dominates: the current figures cannot
   separate ISR cost from the task's own deepest call chain, because the HWM
   is only sampled after the push returns.
4. **`palette` is not validated after `fread`.** A short read leaves stale
   bytes from the previous image in the buffer and silently produces a wrong
   palette. Return values of both `fread` calls are ignored today. Unrelated to
   the crash, but in the same three lines of code.

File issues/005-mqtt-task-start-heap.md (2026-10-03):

# 005 - MQTT client never starts after first-time provisioning (mqtt_task creation fails)

| Field | Value |
|---|---|
| Status | **Fixed** - awaiting on-device confirmation |
| Found | 2026-10-03 |
| Evidence | `/home/savio/run_3.txt` |
| Device log version | `0.4.1`, ESP-IDF v5.4.1, esp32s3 |
| Branch | `fixstuff` |
| Related | [`001-epd-154-heap-exhaustion.md`](./001-epd-154-heap-exhaustion.md), [`003-epd-spi-dma-no-mem.md`](./003-epd-spi-dma-no-mem.md), [`004-security2-srp-double-free-reboot.md`](./004-security2-srp-double-free-reboot.md) |

## Symptom

Provisioning now completes cleanly - the security2 handshake succeeds, Wi-Fi
associates and gets an IP address, SNTP syncs. The device then looks healthy
but never reaches the broker: there is no `MQTT_EVENT_CONNECTED`, and nothing
that the firmware publishes ever arrives.

From `run_3.txt`:

```
I (48950) app: Connected with IP Address:192.168.1.35
I (48950) app: Wi-Fi Up! Cleared binary image QR matrix widget.
I (48950) esp_netif_handlers: sta ip: 192.168.1.35, mask: 255.255.255.0, gw: 192.168.1.1
E (48950) mqtt_client: Error create mqtt task
I (48950) network_prov_mgr: STA Got IP
...
W (54830) BT_HCI: hci cmd send: disconnect: hdl 0x1, rsn:0x13
I (55850) network_prov_mgr: Provisioning stopped
I (55850) network_prov_scheme_ble: BTDM memory released
```

The same log also confirms [`004`](./004-security2-srp-double-free-reboot.md)
is fixed: `I (27060) app: Secured session established!` and no reboot.

## Root cause

`mqtt_client: Error create mqtt task` is emitted by
`esp_mqtt_client_start()` when `xTaskCreate()` returns anything other than
`pdTRUE`:

```c
/* components/mqtt/esp-mqtt/mqtt_client.c:1772 */
if (xTaskCreate(esp_mqtt_task, "mqtt_task", client->config->task_stack, client,
                client->config->task_prio, &client->task_handle) != pdTRUE) {
    ESP_LOGE(TAG, "Error create mqtt task");
```

So the task simply could not be allocated. Two things had to be true for that.

### 1. esp-mqtt asked for 6144 bytes of contiguous internal RAM

`main/mqtt_io.cpp` builds the config with `esp_mqtt_client_config_t mqtt5_cfg = {}`
and never sets `.task.stack_size`, so esp-mqtt falls back to its compiled
default:

```c
/* esp-mqtt/lib/include/mqtt_config.h:45-49 */
#define MQTT_TASK_STACK             (6*1024)
```

`CONFIG_MQTT_TASK_STACK_SIZE` cannot be used instead - it `depends on
MQTT_USE_CUSTOM_CONFIG`, and `CONFIG_MQTT_USE_CUSTOM_CONFIG` is not set. On top
of that, `esp_mqtt_client_init()` had *already* taken roughly 3 KB: the client
struct, config storage, a recursive mutex, an event group, and the default
1024-byte in/out message buffers.

### 2. The Bluetooth controller was still holding that memory

This is the part that only affects first-time provisioning. Inside
`wifi_prov_task` there are two paths that converge on the same
`xEventGroupWaitBits(... WIFI_CONNECTED_EVENT ...)` at `main/provisioning.cpp:688`:

| Boot path | `network_prov_mgr_deinit()` before the IP arrives? | MQTT starts |
|---|---|---|
| Already provisioned (`main/provisioning.cpp:674-685`) | **Yes**, at line 680 | succeeds |
| Fresh provisioning (`main/provisioning.cpp:653-673`) | **No** | **fails** |

The already-provisioned path never starts BLE, so it releases the manager
upfront and BTDM is long gone by the time MQTT starts. The fresh-provisioning
path starts the BLE scheme and then immediately waits for the IP, keeping the
whole Bluedroid + BT controller footprint resident.

Internal heap at that point was already thin:

```
I (3300) app: [HEAP] after provisioning_start: INTERNAL free=126419, largest_blk=32768
```

and BTDM takes a large slice of what is left. The 6144-byte request needs one
contiguous block, which is exactly what a fragmented internal heap stops
providing.

BTDM is only given back when provisioning ends. `esp_network_provisioning`
arms a **30 second** auto-stop timer on `IP_EVENT_STA_GOT_IP`
(`CONFIG_NETWORK_PROV_AUTOSTOP_TIMEOUT=30`, `manager.c:1782`), and in this
capture the provisioning client hung up first at 54830, so:

```
MQTT start attempt at 48950  ->  fails
BTDM released at       55850  ->  6.9 s too late
```

### 3. Nothing checked the result, and nothing retried

`mqtt_io_start()` discarded both return codes and the call was made once,
straight-line, with no retry and no error path. Worse, `esp_mqtt_client_init()`
*had* succeeded, so `app::set_mqtt()` stored a **task-less** client handle.
`app::mqtt_publish()` only null-checks the pointer:

```cpp
/* main/app_common.cpp:31-39 */
if (s_mqtt == nullptr) return false;
int msg_id = esp_mqtt_client_publish(s_mqtt, topic, payload, 0, qos, retain);
return msg_id >= 0;
```

so status/LED/OTA publishes would enqueue into a client with no task and
**report success while delivering nothing**. And because `app::fire_on_connect()`
only runs from `MQTT_EVENT_CONNECTED`, the notification LED never handed back to
MQTT control either.

## Fix

### Retry the start until BTDM is released

`mqtt_io_start()` now returns `esp_err_t` (`main/mqtt_io.hpp`), and
`wifi_prov_task` retries it 1 s apart, 60 times
(`MQTT_START_MAX_ATTEMPTS`, `main/provisioning.cpp:129-134`). That covers both
ways provisioning ends - the client hanging up (a few seconds) and the 30 s
auto-stop timer.

Provisioning teardown is deliberately **not** forced. `network_prov_manager`
offers `network_prov_mgr_stop_provisioning()` and
`network_prov_mgr_disable_auto_stop()` for this, but the component docs note the
auto-stop delay exists so the client can still query network state after
handing over credentials. Ending BLE early risks truncating that exchange, so the
retry waits for the memory instead.

### Report failure, destroy the partial client, never leave a dead handle

`mqtt_io_start()` now checks `esp_mqtt_client_init()` and
`esp_mqtt_client_start()`, and on failure clears `app::set_mqtt(NULL)` before
`esp_mqtt_client_destroy()`. That closes the false-success path and stops the
~3 KB of client state leaking on every attempt. If all attempts are exhausted
the device logs one error and keeps running without cloud connectivity rather
than looping forever.

`mqtt_register_cmd()` is safe to call again on each attempt - it is a map write
(`main/mqtt_io.cpp:20-23`) - and subscriptions are derived per client inside
`MQTT_EVENT_CONNECTED`, so a rebuilt client cannot double-subscribe.

### Return headroom to internal RAM

`CONFIG_ESP_WIFI_DYNAMIC_RX_BUFFER_NUM` reduced from the default 32 to 16 in
`sdkconfig.defaults`. Wi-Fi RX buffers were the single largest internal-DMA
consumer, and returning roughly 25 KB gives the Bluetooth controller and the
esp-mqtt task real margin instead of relying on a lucky fragmentation pattern.
This is the item previously deferred in
[`003`](./003-epd-spi-dma-no-mem.md#follow-ups-not-done-here); it trades some
Wi-Fi RX throughput.

## Follow-ups not done here

1. **`app::mqtt_publish()` can still report false success.** If the broker is
   unreachable, publishes queue into the outbox and return a valid `msg_id`
   until the outbox fills. A "connected" flag checked in `mqtt_publish()` would
   make this honest.
2. **The failure is only visible by log.** Nothing surfaces "MQTT is down" on
   the device; `status_ctrl` could publish/report it once
   `MQTT_EVENT_CONNECTED` has been seen at least once.
3. **`esp_mqtt_client_start()` is still the only heap gate.** If the internal
   heap is ever too fragmented even after BTDM release, the retry will simply
   run out of attempts. Worth re-measuring `largest_blk` against the 6144-byte
   request in the `mqtt_io_start failed, retrying` log lines added here.

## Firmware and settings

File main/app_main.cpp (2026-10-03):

#include <string>

#include "freertos/FreeRTOS.h"
#include "freertos/task.h"

#include "esp_log.h"
#include "esp_err.h"
#include "esp_event.h"
#include "esp_netif.h"
#include "esp_wifi.h"
#include "nvs_flash.h"

#include "driver/gpio.h"

#include "user_config.h"
#include "user_app.h"
#include "sdcard_manager.hpp"

#include "app_common.hpp"
#include "audio_ctrl.hpp"
#include "config_store.hpp"
#include "display_ctrl.hpp"
#include "download_mgr.hpp"
#include "identity.hpp"
#include "led_ctrl.hpp"
#include "ota_ctrl.hpp"
#include "provisioning.hpp"
#include "sensor_ctrl.hpp"
#include "status_ctrl.hpp"
#include "time_ctrl.hpp"
#include "ui_port.hpp"

static const char *TAG = "app";

#define RESET_BUTTON_GPIO   GPIO_NUM_3  // Factory-reset / re-provision button
#define BUTTON_PRESSED_LEVEL 0           // Active-low configuration

/**
 * @brief Checks if the reset button is being held down at boot.
 * @return true if pressed, false otherwise.
 */
static bool check_reset_button_at_boot(void)
{
	gpio_config_t io_conf = {};
	io_conf.intr_type = GPIO_INTR_DISABLE;
	io_conf.mode = GPIO_MODE_INPUT;
	io_conf.pin_bit_mask = (1ULL << RESET_BUTTON_GPIO);
	io_conf.pull_down_en = GPIO_PULLDOWN_DISABLE;
	io_conf.pull_up_en = GPIO_PULLUP_ENABLE;
	gpio_config(&io_conf);

	// Allow the lines to settle and give the user a tiny 200ms window
	// to make sure they are intentionally holding the button down
	vTaskDelay(pdMS_TO_TICKS(200));

	if (gpio_get_level(RESET_BUTTON_GPIO) == BUTTON_PRESSED_LEVEL)
	{
		ESP_LOGW("RESET", "Reset button detected down at power-up! Holding for confirmation...");
		// Optional: Wait an extra second to avoid accidental triggers
		vTaskDelay(pdMS_TO_TICKS(1000));
		return (gpio_get_level(RESET_BUTTON_GPIO) == BUTTON_PRESSED_LEVEL);
	}

	return false;
}

/**
 * @brief Starts the subsystems that have nothing to do with provisioning.
 *
 * Deliberately NOT called at boot. While the provisioning BLE transport is up
 * the BT controller has taken ~90 KB of internal RAM out of a pool that
 * esp_wifi_init() had already cut by ~37 KB, leaving only a few hundred bytes
 * of contiguous DMA-capable memory. Measured on the ESP32-S3 during a
 * prov-scan session:
 *
 *   after network_prov_mgr_start_provisioning  BTCAP largest_blk = 22528
 *   BLE connected (pre-keygen)                 BTCAP largest_blk =  544
 *   session established (pre prov-scan)        BTCAP largest_blk =  336
 *
 * At 336 contiguous bytes the station cannot allocate the RX buffers needed to
 * accept an association response, so Wi-Fi association fails with
 * "Wi-Fi station authentication failed" even though the credentials are right.
 * The same exhaustion makes AES-GCM response encryption (esp_aes) and the BT
 * controller's own allocations fail, which is why the SSID list never arrives.
 *
 * These tasks are deferred until the station has an IP, so they never compete
 * with BTDM. Ordering below is load-bearing:
 *   - sensor_ctrl claims the shared I2C bus, so it must go first;
 *   - audio_ctrl and time_ctrl both attach to that same bus.
 */
static void start_deferred_subsystems(void)
{
	// Must run before audio_ctrl::start(): the codec board support installs the
	// I2C bus itself when it finds none, so the first caller wins. Claiming it
	// here, off the app_main boot path, keeps that single-threaded.
	sensor_ctrl::start();
	audio_ctrl::start();

	// Must run after config_store_load() and after the event loop exists, so the
	// timezone it restores is not overwritten by the compiled-in default. The RTC
	// is on the same bus sensor_ctrl just claimed, so it comes second.
	time_ctrl::start();
}

extern "C" void app_main(void)
{

	// Derive device ID from the factory-programmed base MAC address.
	// Must run before MQTT or any topic-dependent code.
	identity_init();

	// Sensible defaults + MQTT/download/on-connect registrations so every
	// subsystem is wired before the provisioning task can bring up Wi-Fi.
	led_ctrl::init();
	display_ctrl::init();
	audio_ctrl::init();
	ota_ctrl::init();
	status_ctrl::init();
	sensor_ctrl::init();
	time_ctrl::init();

	user_app_init();
	user_app_display_init();

	download::log_heap_info("after user_app_init");

	bool dynamic_factory_reset = check_reset_button_at_boot();

	if (dynamic_factory_reset)
	{
		ESP_LOGW(TAG, "=================================================");
		ESP_LOGW(TAG, "FACTORY RESET TRIGGERED! Wiping system profiles...");
		ESP_LOGW(TAG, "=================================================");

		// This completely wipes the default NVS partition where credentials live
		ESP_ERROR_CHECK(nvs_flash_erase());
	}

	SDCardConfig sd_config;
	sd_config.mountPoint = SD_MOUNT_POINT;
	sd_config.maxOpenFiles = 5;
	sd_config.allocationUnitSize = 16 * 1024;
	sd_config.pinCmd = SDMMC_CMD_PIN;
	sd_config.pinClk = SDMMC_CLK_PIN;
	sd_config.pinD0 = SDMMC_D0_PIN;

	IFileSystem *sdcard = new SDCardManager(sd_config);
	app::set_sdcard(sdcard);

	if (sdcard->mount())
	{
		ESP_LOGI(TAG, "SD card mounted successfully. You can now perform file operations.");
		config_store_load();
	}
	else
	{
		ESP_LOGE(TAG, "Failed to mount SD card. Check the connections and try again.");
	}

	download::log_heap_info("after SD mount + config_store_load");

	/* Epaper display initialization */
	ui_port_init();

	download::log_heap_info("after ui_port_init");

	/* Initialize NVS partition */
	esp_err_t ret = nvs_flash_init();
	if (ret == ESP_ERR_NVS_NO_FREE_PAGES || ret == ESP_ERR_NVS_NEW_VERSION_FOUND)
	{
		/* NVS partition was truncated
		 * and needs to be erased */
		ESP_ERROR_CHECK(nvs_flash_erase());

		/* Retry nvs_flash_init */
		ESP_ERROR_CHECK(nvs_flash_init());
	}

	/* Handle OTA cycle results from the factory app (mark VALID, clear stale intents) */
	ota_ctrl::init_boot_state();

	/* Initialize TCP/IP */
	ESP_ERROR_CHECK(esp_netif_init());

	/*
	 * The probes from here to display_ctrl::start() bracket the single largest
	 * internal-memory drop on boot (~74 KB observed on the ESP32-S3). Without
	 * them that whole window is unaccounted for and there is no way to tell
	 * Wi-Fi driver static buffers from LVGL. esp_wifi_init() is the prime
	 * suspect: the static RX/TX/mgmt buffers it allocates are never freed
	 * until esp_wifi_deinit(), and BLE provisioning then has to share what
	 * is left with the AES DMA descriptors and the BT controller.
	 */
	download::log_heap_info("after esp_netif_init");

	/* Initialize the event loop */
	ESP_ERROR_CHECK(esp_event_loop_create_default());

	download::log_heap_info("after esp_event_loop_create_default");

	/* Register our event handler for Wi-Fi, IP and Provisioning related events */
	provisioning_register_core_events();

	/* Initialize Wi-Fi including netif with default config */
	esp_netif_create_default_wifi_sta();
#ifdef CONFIG_EXAMPLE_PROV_TRANSPORT_SOFTAP
	esp_netif_create_default_wifi_ap();
#endif /* CONFIG_EXAMPLE_PROV_TRANSPORT_SOFTAP */

	download::log_heap_info("after esp_netif_create_default_wifi_sta");

	wifi_init_config_t cfg = WIFI_INIT_CONFIG_DEFAULT();
	ESP_ERROR_CHECK(esp_wifi_init(&cfg));

	download::log_heap_info("after esp_wifi_init");

	// 1. Initialize the UI and create widgets FIRST while holding the lock.
	//    MUST run before the provisioning task spawns: user_ui_init() calls
	//    lv_obj_clean(lv_screen_active()), which would delete the QR widget
	//    pushed by wifi_prov_task if the ordering were reversed.
	if (ui_lock(-1))
	{
		user_ui_init(); // <--- Instantiates 'dynamic_epd_image' safely!

		ui_create_wifi_icon();

		ui_unlock();
	}

	// 2. Start the display/LED feedback before provisioning: the QR overlay the
	//    user scans is drawn on this stack, and the LED pulses report provisioning
	//    progress, so both are provisioning-related and stay up.
	xTaskCreatePinnedToCore(example_lvgl_port_task, "LVGL", 8192, NULL, 4, NULL, 1);
	led_ctrl::start();
	download::log_heap_info("after led_ctrl::start");
	display_ctrl::start();
	xTaskCreate(ui_overlay_task, "ui_overlay", 4096, NULL, 4, NULL);
	download::log_heap_info("after display_ctrl::start");
	display_ctrl::boot_kick_if_active();

	// 3. Now start provisioning (WiFi/BLE) after display is ready. Audio,
	//    sensors and the RTC are started by start_deferred_subsystems() once the
	//    station has an IP -- see the comment on that function.
	provisioning_set_post_provision_hook(start_deferred_subsystems);
	provisioning_start();
	download::log_heap_info("after provisioning_start");
}

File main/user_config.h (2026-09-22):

#ifndef USER_CONFIG_H
#define USER_CONFIG_H

#define EPD_SPI_NUM SPI2_HOST
#define ESP32_I2C_DEV_NUM I2C_NUM_0

#define EPD_WIDTH 200
#define EPD_HEIGHT 200

/*EPD port Init*/
#define EPD_DC_PIN GPIO_NUM_10
#define EPD_CS_PIN GPIO_NUM_11
#define EPD_SCK_PIN GPIO_NUM_12
#define EPD_MOSI_PIN GPIO_NUM_13
#define EPD_RST_PIN GPIO_NUM_9
#define EPD_BUSY_PIN GPIO_NUM_8

/*DEV POWER init*/
#define EPD_PWR_PIN GPIO_NUM_6
#define Audio_PWR_PIN GPIO_NUM_42
#define VBAT_PWR_PIN GPIO_NUM_17

#define BOOT_BUTTON_PIN GPIO_NUM_0
#define PWR_BUTTON_PIN GPIO_NUM_3

/*Low-power wake-up*/
#define ext_wakeup_pin_1 GPIO_NUM_0

/*ESP32 I2C Init*/
#define ESP32_I2C_SDA_PIN GPIO_NUM_47
#define ESP32_I2C_SCL_PIN GPIO_NUM_48

/*lvgl init*/
#define EXAMPLE_LVGL_TICK_PERIOD_MS 5
#define EXAMPLE_LVGL_TASK_MAX_DELAY_MS 500
#define EXAMPLE_LVGL_TASK_MIN_DELAY_MS 100

/*i2c dev*/
#define I2C_RTC_DEV_Address 0x51
#define I2C_SHTC3_DEV_Address 0x70

/*SDMMC*/
#define SDMMC_D0_PIN GPIO_NUM_40
#define SDMMC_CLK_PIN GPIO_NUM_39
#define SDMMC_CMD_PIN GPIO_NUM_41

#define RGB_LED_STRIP_PIN 2

#endif // !USER_CONFIG_H

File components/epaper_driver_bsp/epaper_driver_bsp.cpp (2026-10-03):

#include <stdio.h>
#include <string.h>
#include <math.h>
#include "freertos/FreeRTOS.h"
#include "epaper_driver_bsp.h"
#include "esp_log.h"

#include "esp_heap_caps.h" 
#include "esp_err.h"
#include "esp_system.h"

static const char *TAG = "driver";

void epaper_driver_display::EPD_LogHeap(const char *context) {
    ESP_LOGI(TAG, "[HEAP] %s: total_free=%u, total_min=%u | INTERNAL free=%u, largest_blk=%u | DMA free=%u | SPIRAM free=%u",
             context,
             (unsigned)esp_get_free_heap_size(),
             (unsigned)esp_get_minimum_free_heap_size(),
             (unsigned)heap_caps_get_free_size(MALLOC_CAP_INTERNAL | MALLOC_CAP_8BIT),
             (unsigned)heap_caps_get_largest_free_block(MALLOC_CAP_INTERNAL | MALLOC_CAP_8BIT),
             (unsigned)heap_caps_get_free_size(MALLOC_CAP_DMA),
             (unsigned)heap_caps_get_free_size(MALLOC_CAP_SPIRAM));
}

const uint8_t WF_Full_1IN54[159] =
{											
    0x80,	0x48,	0x40,	0x0,	0x0,	0x0,	0x0,	0x0,	0x0,	0x0,	0x0,	0x0,
    0x40,	0x48,	0x80,	0x0,	0x0,	0x0,	0x0,	0x0,	0x0,	0x0,	0x0,	0x0,
    0x80,	0x48,	0x40,	0x0,	0x0,	0x0,	0x0,	0x0,	0x0,	0x0,	0x0,	0x0,
    0x40,	0x48,	0x80,	0x0,	0x0,	0x0,	0x0,	0x0,	0x0,	0x0,	0x0,	0x0,
    0x0,	0x0,	0x0,	0x0,	0x0,	0x0,	0x0,	0x0,	0x0,	0x0,	0x0,	0x0,
    0xA,	0x0,	0x0,	0x0,	0x0,	0x0,	0x0,					
    0x8,	0x1,	0x0,	0x8,	0x1,	0x0,	0x2,					
    0xA,	0x0,	0x0,	0x0,	0x0,	0x0,	0x0,					
    0x0,	0x0,	0x0,	0x0,	0x0,	0x0,	0x0,					
    0x0,	0x0,	0x0,	0x0,	0x0,	0x0,	0x0,					
    0x0,	0x0,	0x0,	0x0,	0x0,	0x0,	0x0,					
    0x0,	0x0,	0x0,	0x0,	0x0,	0x0,	0x0,					
    0x0,	0x0,	0x0,	0x0,	0x0,	0x0,	0x0,					
    0x0,	0x0,	0x0,	0x0,	0x0,	0x0,	0x0,					
    0x0,	0x0,	0x0,	0x0,	0x0,	0x0,	0x0,					
    0x0,	0x0,	0x0,	0x0,	0x0,	0x0,	0x0,					
    0x0,	0x0,	0x0,	0x0,	0x0,	0x0,	0x0,					
    0x22,	0x22,	0x22,	0x22,	0x22,	0x22,	0x0,	0x0,	0x0,			
    0x22,	0x17,	0x41,	0x0,	0x32,	0x20
};

unsigned char WF_PARTIAL_1IN54_0[159] =
{
    0x0,0x40,0x0,0x0,0x0,0x0,0x0,0x0,0x0,0x0,0x0,0x0,
    0x80,0x80,0x0,0x0,0x0,0x0,0x0,0x0,0x0,0x0,0x0,0x0,
    0x40,0x40,0x0,0x0,0x0,0x0,0x0,0x0,0x0,0x0,0x0,0x0,
    0x0,0x80,0x0,0x0,0x0,0x0,0x0,0x0,0x0,0x0,0x0,0x0,
    0x0,0x0,0x0,0x0,0x0,0x0,0x0,0x0,0x0,0x0,0x0,0x0,
    0xF,0x0,0x0,0x0,0x0,0x0,0x0,
    0x1,0x1,0x0,0x0,0x0,0x0,0x0,
    0x0,0x0,0x0,0x0,0x0,0x0,0x0,
    0x0,0x0,0x0,0x0,0x0,0x0,0x0,
    0x0,0x0,0x0,0x0,0x0,0x0,0x0,
    0x0,0x0,0x0,0x0,0x0,0x0,0x0,
    0x0,0x0,0x0,0x0,0x0,0x0,0x0,
    0x0,0x0,0x0,0x0,0x0,0x0,0x0,
    0x0,0x0,0x0,0x0,0x0,0x0,0x0,
    0x0,0x0,0x0,0x0,0x0,0x0,0x0,
    0x0,0x0,0x0,0x0,0x0,0x0,0x0,
    0x0,0x0,0x0,0x0,0x0,0x0,0x0,
    0x22,0x22,0x22,0x22,0x22,0x22,0x0,0x0,0x0,
    0x02,0x17,0x41,0xB0,0x32,0x28,
};

epaper_driver_display::epaper_driver_display(int width, int height, custom_lcd_spi_t _lcd_spi_data) : 
    lcd_spi_data(_lcd_spi_data),
    Width(width),
    Height(height) {

    ESP_LOGI(TAG, "Initialize SPI");
	spi_port_init();
	spi_gpio_init();

    buffer = (uint8_t *)heap_caps_malloc(lcd_spi_data.buffer_len, MALLOC_CAP_SPIRAM);
	assert(buffer);
}

epaper_driver_display::epaper_driver_display(int width, int height, custom_lcd_spi_t _lcd_spi_data, uint8_t *external_buffer) : 
    lcd_spi_data(_lcd_spi_data),
    Width(width),
    Height(height) {

    ESP_LOGI(TAG, "Initialize SPI (external buffer)");
	spi_port_init();
	spi_gpio_init();

    buffer = external_buffer;
	assert(buffer != NULL);
}

epaper_driver_display::~epaper_driver_display() {

}

void epaper_driver_display::spi_gpio_init() {
    int rst = lcd_spi_data.rst;
    int cs = lcd_spi_data.cs;
    int dc = lcd_spi_data.dc;
    int busy = lcd_spi_data.busy;

    gpio_config_t gpio_conf = {};
	gpio_conf.intr_type = GPIO_INTR_DISABLE;
	gpio_conf.mode = GPIO_MODE_OUTPUT;
	gpio_conf.pin_bit_mask = (0x1ULL<<rst) | (0x1ULL<<dc) | (0x1ULL<<cs);
	gpio_conf.pull_down_en = GPIO_PULLDOWN_DISABLE;
	gpio_conf.pull_up_en = GPIO_PULLUP_ENABLE;
	ESP_ERROR_CHECK_WITHOUT_ABORT(gpio_config(&gpio_conf));

	gpio_conf.mode = GPIO_MODE_INPUT;
	gpio_conf.pin_bit_mask = (0x1ULL<<busy);
	ESP_ERROR_CHECK_WITHOUT_ABORT(gpio_config(&gpio_conf));

    set_rst_1();
}

void epaper_driver_display::spi_port_init() {
    int mosi = lcd_spi_data.mosi;
    int scl = lcd_spi_data.scl;
    int spi_host = lcd_spi_data.spi_host;
    esp_err_t ret;
  	spi_bus_config_t buscfg = {};
  	  	buscfg.miso_io_num = -1;
  	  	buscfg.mosi_io_num = mosi;
  	  	buscfg.sclk_io_num = scl;
  	  	buscfg.quadwp_io_num = -1;
  	  	buscfg.quadhd_io_num = -1;
  	  	buscfg.max_transfer_sz = Width * Height;

  	spi_device_interface_config_t devcfg = {};
  	  	devcfg.spics_io_num = -1;
  	  	devcfg.clock_speed_hz = 40 * 1000 * 1000;  //Clock out at 10 MHz
  	  	devcfg.mode = 0;                           //SPI mode 0
  	  	devcfg.queue_size = 7;                     //We want to be able to queue 7 transactions at a time

  	ret = spi_bus_initialize((spi_host_device_t)spi_host, &buscfg, SPI_DMA_CH_AUTO);
  	ESP_ERROR_CHECK(ret);
  	ret = spi_bus_add_device((spi_host_device_t)spi_host, &devcfg, &spi);
  	ESP_ERROR_CHECK(ret);
}

void epaper_driver_display::read_busy() {
    int busy = lcd_spi_data.busy;
    while(gpio_get_level((gpio_num_t)busy) == 1) 
	{
        vTaskDelay(pdMS_TO_TICKS(5));   //LOW: idle, HIGH: busy
    }
}

// Retry a failed SPI transfer once. A failure here means the panel keeps
// whatever was last latched, so a single transient NO_MEM silently strands the
// display on a stale frame while LVGL is told the flush succeeded.
esp_err_t epaper_driver_display::spi_transmit_with_retry(spi_transaction_t *t, const char *what) {
    esp_err_t ret = spi_device_polling_transmit(spi, t);
    if (ret == ESP_OK) {
        return ret;
    }
    ESP_LOGW(TAG, "%s failed: %s - retrying once", what, esp_err_to_name(ret));
    vTaskDelay(pdMS_TO_TICKS(50));
    ret = spi_device_polling_transmit(spi, t);
    if (ret != ESP_OK) {
        ESP_LOGE(TAG, "%s failed again after retry: %s - panel will show a stale frame",
                 what, esp_err_to_name(ret));
        EPD_LogHeap(what);
    }
    return ret;
}

void epaper_driver_display::SPI_SendByte(uint8_t data) {
	spi_transaction_t t;
	memset(&t, 0, sizeof(t));
    t.length = 8;
    t.tx_buffer = &data;
    char what[24];
    snprintf(what, sizeof(what), "SPI_SendByte(0x%02x)", data);
    spi_transmit_with_retry(&t, what);
}

void epaper_driver_display::EPD_SendData(uint8_t data) {
    set_dc_1();

  	set_cs_0();
  	SPI_SendByte(data);
  	set_cs_1();
}

void epaper_driver_display::EPD_SendCommand(uint8_t command) {
    set_dc_0();
   	set_cs_0();
   	SPI_SendByte(command);
  	set_cs_1();
}

void epaper_driver_display::writeBytes(uint8_t *buffer,int len) {
    set_dc_1();
  	set_cs_0();
   	spi_transaction_t t;
    memset(&t, 0, sizeof(t));
    t.length = 8 * len;
   	t.tx_buffer = buffer;
    char what[32];
    snprintf(what, sizeof(what), "writeBytes(%d bytes)", len);
    spi_transmit_with_retry(&t, what);
  	set_cs_1();
}
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

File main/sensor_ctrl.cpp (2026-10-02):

#include <cstdio>
#include <cstdlib>
#include <mutex>

#include "freertos/FreeRTOS.h"
#include "freertos/task.h"

#include "esp_err.h"
#include "esp_log.h"
#include "esp_timer.h"

#include "cJSON.h"

#include "i2c_bsp.h"
#include "shtc3_bsp.h"
#include "user_config.h"

#include "app_common.hpp"
#include "identity.hpp"

#include "sensor_ctrl.hpp"

static const char *TAG = "app";

// Five minutes. The sensor is read on boot so a freshly flashed device has a
// value to report right away, then slowly from there.
#define SENSOR_SAMPLE_INTERVAL_MS 300000

// The SHTC3 shares the bus with the audio codec, which is still registering the
// ES8311 at this point in boot. Sweeping and sampling before that finishes
// measures a bus that is still coming up, so both wait it out first.
#define SENSOR_BUS_SETTLE_MS 2000

// A read can lose a single race with the codec's own register writes, so retry
// inside one cycle before giving up on it for the next five minutes.
#define SENSOR_READ_ATTEMPTS 3
#define SENSOR_READ_RETRY_MS 200

// 0x00-0x07 and 0x78-0x7F are reserved blocks: a device answering there is a
// wiring fault, not a device worth reporting.
#define SENSOR_SCAN_FIRST_ADDR 0x08
#define SENSOR_SCAN_LAST_ADDR 0x77
#define SENSOR_SCAN_MAX_FOUND 16

namespace
{

    // The last reading that passed its CRC and range check. Guarded because the
    // sampling task writes it while MQTT commands read it.
    struct sensor_state_t
    {
        std::mutex mutex;
        bool valid = false;
        float temperature_c = 0.0f;
        float humidity_pct = 0.0f;
        uint64_t sampled_at_ms = 0;
    };

    sensor_state_t g_state;

    // One line naming every device that answered on the shared bus. This is the
    // first thing to read when a unit does not report a temperature: an address
    // missing from the list is a hardware problem, an address present but a read
    // that still fails is one of ours.
    // Addresses the sweep is expected to find, because this unit's own devices
    // occupy them and at least one of them has just been read successfully. Checked
    // afterwards so a sweep that disagrees with the hardware is reported as a
    // defective sweep rather than a dead device.
    struct known_device_t
    {
        uint8_t addr;
        const char *what;
    };
    const known_device_t known[] = {
        {I2C_SHTC3_DEV_Address, "SHTC3, read at every sample"},
        {I2C_RTC_DEV_Address, "PCF85063, attached at boot"},
    };

    bool scan_contains(const uint8_t *list, size_t count, uint8_t addr)
    {
        for (size_t i = 0; i < count; i++)
        {
            if (list[i] == addr)
            {
                return true;
            }
        }
        return false;
    }

    // Every boot, so a unit that stops reporting can be diagnosed from its log alone.
    // Deliberately before the first sample: it is the SHTC3's address that tells us
    // whether a later read failure is the bus or the sensor, and a sweep run after a
    // successful read could not tell a dead sensor from a broken bus.
    void sensor_scan_bus()
    {
        const size_t known_count = sizeof(known) / sizeof(known[0]);
        uint8_t found[SENSOR_SCAN_MAX_FOUND] = {0};
        size_t found_count = 0;

        const esp_err_t err = i2c_bsp_scan(ESP32_I2C_DEV_NUM, SENSOR_SCAN_FIRST_ADDR, SENSOR_SCAN_LAST_ADDR,
                                           found, sizeof(found), &found_count);
        if (err == ESP_ERR_INVALID_STATE)
        {
            ESP_LOGW(TAG, "I2C scan skipped, no master bus on port %d", ESP32_I2C_DEV_NUM);
            return;
        }

        char list[sizeof(found) * 5] = {0};
        size_t used = 0;
        for (size_t i = 0; i < found_count; i++)
        {
            used += snprintf(list + used, sizeof(list) - used, "%s0x%02X", (i == 0) ? "" : " ", found[i]);
        }

        if (err == ESP_ERR_TIMEOUT)
        {
            ESP_LOGW(TAG, "I2C scan on SDA %d / SCL %d: bus timed out, SDA held low or pull-ups missing (so far: %s)",
                     ESP32_I2C_SDA_PIN, ESP32_I2C_SCL_PIN, list);
            return;
        }
        if (err != ESP_OK)
        {
            ESP_LOGW(TAG, "I2C scan on SDA %d / SCL %d failed: %s (so far: %s)", ESP32_I2C_SDA_PIN, ESP32_I2C_SCL_PIN,
                     esp_err_to_name(err), list);
            return;
        }
        if (found_count == 0)
        {
            ESP_LOGW(TAG, "I2C scan on SDA %d / SCL %d: no device answered, check pull-ups and wiring",
                     ESP32_I2C_SDA_PIN, ESP32_I2C_SCL_PIN);
            return;
        }

        ESP_LOGI(TAG, "I2C scan on SDA %d / SCL %d: %s", ESP32_I2C_SDA_PIN, ESP32_I2C_SCL_PIN, list);

        // An address this unit has already talked to successfully, and is still
        // reported as reading fine from, but which the sweep did not find. That is a
        // sweep defect, not a hardware fault, and it is the difference between
        // "sensor died" and "the diagnostic is unreliable".
        for (size_t i = 0; i < known_count; i++)
        {
            if (!scan_contains(found, found_count, known[i].addr))
            {
                ESP_LOGW(TAG, "sweep missed 0x%02X (%s), which just answered; the sweep is "
                              "unreliable here, not the device",
                         known[i].addr, known[i].what);
            }
        }
    }

    // Reads the sensor and, on success, refreshes the cache. A read that keeps
    // failing is logged and otherwise ignored: the retained evt/sensor message is
    // more useful stale than overwritten with nulls, and the next tick tries again.
    void sensor_sample()
    {
        float temperature_c = 0.0f;
        float humidity_pct = 0.0f;
        esp_err_t err = ESP_FAIL;

        for (int attempt = 1; attempt <= SENSOR_READ_ATTEMPTS; attempt++)
        {
            err = shtc3_read(&temperature_c, &humidity_pct);
            if (err == ESP_OK)
            {
                break;
            }
            if (attempt < SENSOR_READ_ATTEMPTS)
            {
                ESP_LOGW(TAG, "SHTC3 read failed (%s), retrying in %d ms", esp_err_to_name(err), SENSOR_READ_RETRY_MS);
                vTaskDelay(pdMS_TO_TICKS(SENSOR_READ_RETRY_MS));
            }
        }

        if (err != ESP_OK)
        {
            ESP_LOGW(TAG, "SHTC3 read failed after %d attempts: %s", SENSOR_READ_ATTEMPTS, esp_err_to_name(err));
            // shtc3_present() logs whether the sensor is still on the bus, which is
            // what separates a dead sensor from a measurement this module could not
            // complete.
            shtc3_present();
            return;
        }

        {
            std::lock_guard<std::mutex> lock(g_state.mutex);
            g_state.valid = true;
            g_state.temperature_c = temperature_c;
            g_state.humidity_pct = humidity_pct;
            g_state.sampled_at_ms = (uint64_t)(esp_timer_get_time() / 1000);
        }
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

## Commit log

2026-03-15 Display to epd
    [partitions.csv]
2026-05-17 v1 hardware
    [.step, board_theLink.kicad_pcb, board_theLink.kicad_sch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]
2026-05-21 use epaper lvgl baseline
    [.step, board_theLink.kicad_pcb, board_theLink.kicad_sch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]
2026-06-05 define command and run led task on instruction from mqtt
2026-06-24 RGB LED Notifications added
2026-08-21 hardware design added
    [Adafruit_NeoPixelRing16.step, theLink.FCStd, theLink_v2.FCStd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]
2026-09-22 - Updates to firmware update process - Change to the Reset Provision button - Include a script to flash app + factory app together
    [partitions.csv, partitions_dev.csv]
2026-09-27 Refactor main file Add finer control to the RGB LED ring Update to the OTA process to support rollbacks Device ID uses MAC address Added command to get status of the device
2026-09-27 removed old CAD designs
    [theLink.FCStd, theLink_v2.step, theLink_v2.stl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]
2026-09-29 - Adds the SHTC3 module support - Modifications to the status response - i2c bus start moved out of audio codec component
2026-09-30 fixes shtc3 read issues
    [i2c_bsp.c, sensor_ctrl.cpp, shtc3_bsp.c]
2026-10-02 Time keeping using NTP
    Read from a NTP server and keep time
    PCF85063 Is initialized but needs to have VBAT power to keep time without the USB power
2026-10-03 Memory issues fixes (#7)
    Fix MQTT task issues
    Fix heap corruption due to WiFI BLE stack usage
    Fix display stack loss due to interrupt piling
    [app_main.cpp, epaper_driver_bsp.cpp]
2026-10-03 Fix provisioning crash at wifi scan
    [app_main.cpp]
